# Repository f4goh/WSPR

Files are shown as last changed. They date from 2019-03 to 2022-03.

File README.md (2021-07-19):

**WSPR beacon on breadboard**

[link to hamprojects web site](https://hamprojects.wordpress.com/2019/06/02/wspr-beacon/)

*f4goh@orange.fr*

**Add FST4W for Antonio (IK1HGI) and new library for OLED**

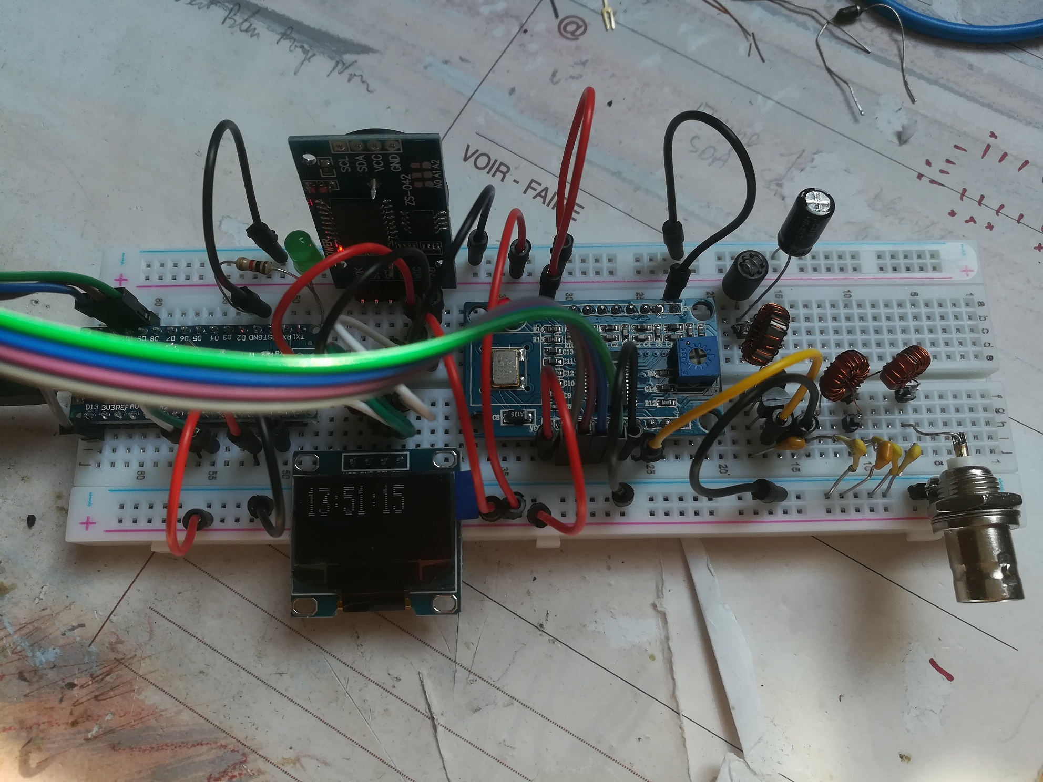
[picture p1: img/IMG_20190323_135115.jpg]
wspr wspr finsished


## Wiring ##

- Wire the schematics below

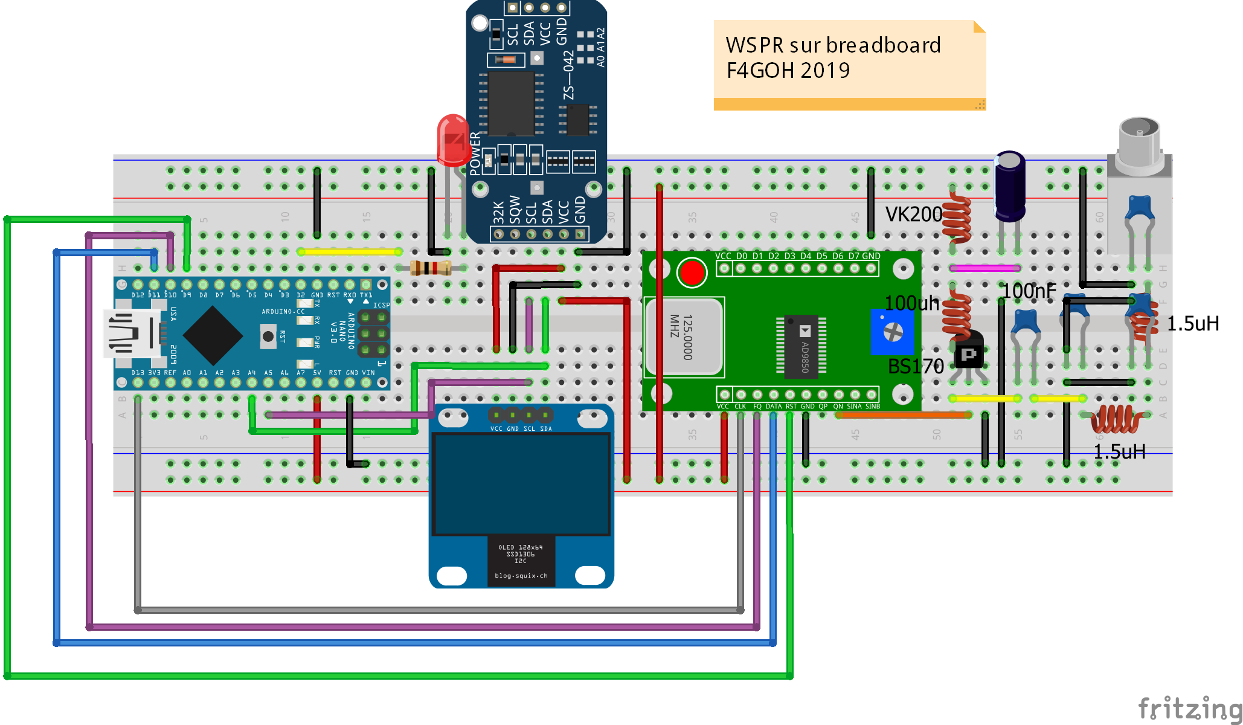
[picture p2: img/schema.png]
sch


- Adjust output filter as filter design calculation

[filter design](http://tonnesoftware.com/svcfilter.html) 

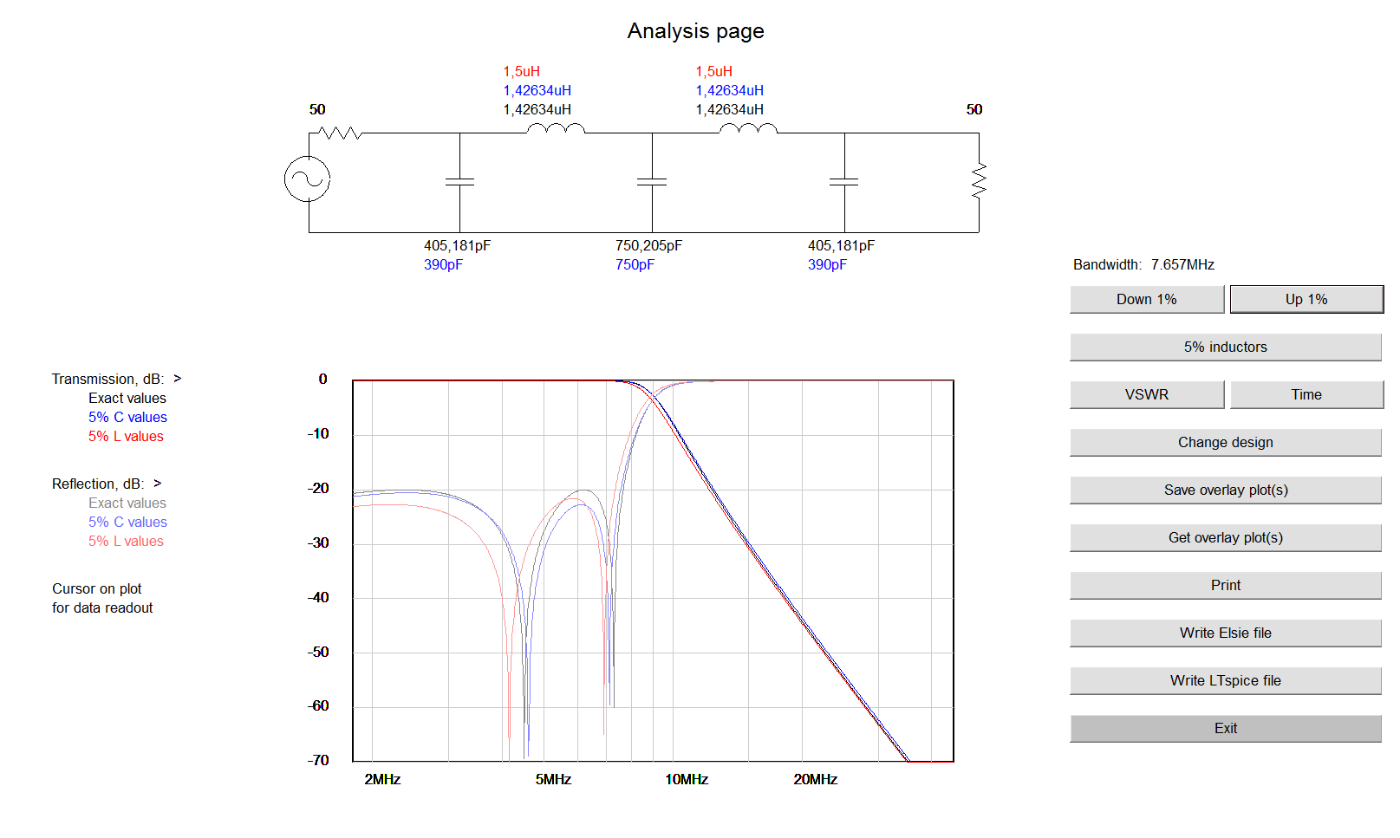
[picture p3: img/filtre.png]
filter


- Use mini tore calculator to find inductor turns

[mini tore calculator](https://constructions.f6fkn.com/downloads/minirk12-install.exe) 

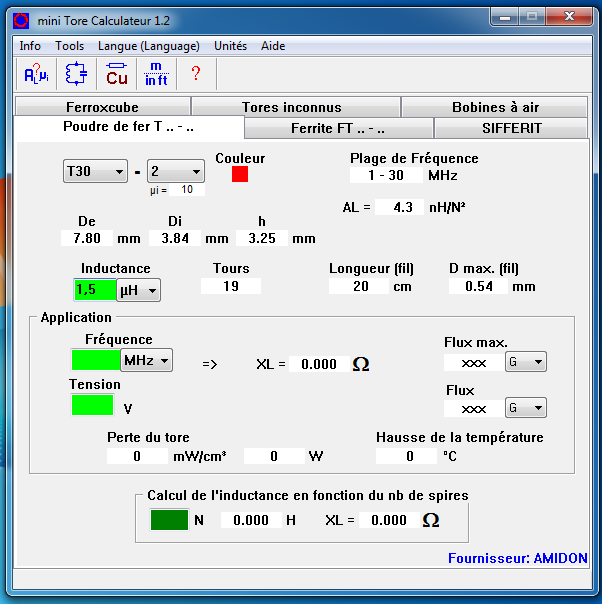
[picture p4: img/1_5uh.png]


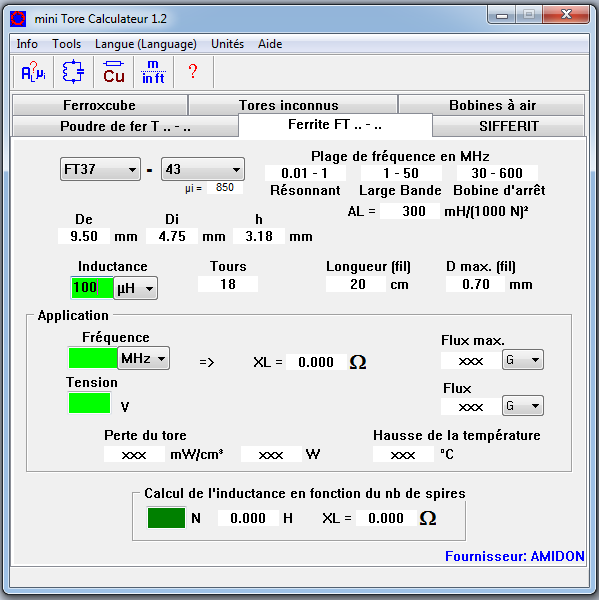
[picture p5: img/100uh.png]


- Check filter with a VNA (optional)

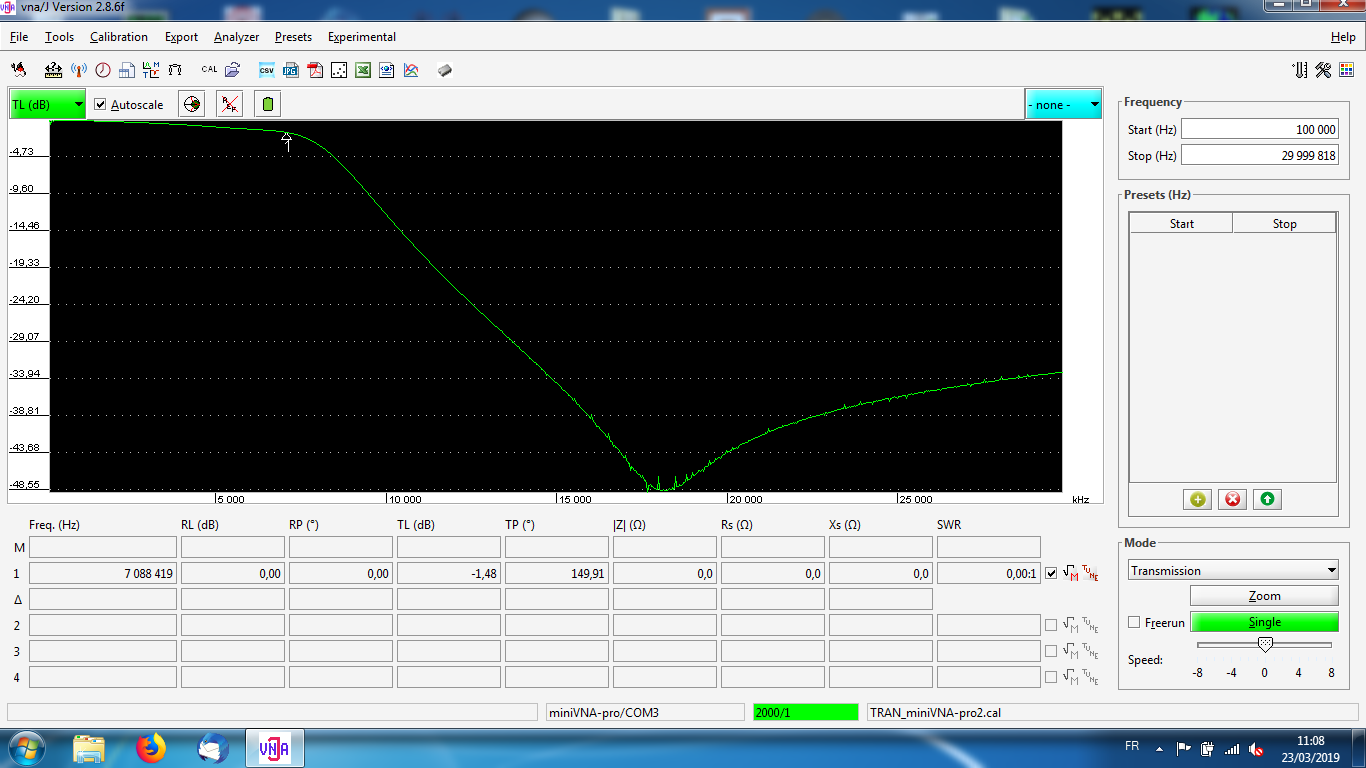
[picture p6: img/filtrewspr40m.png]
vna


## Programming ##

- Copy libraries files into Arduino/library folder

- run wspr.bat put your callsign, locator and power and generate symbols.

symbols wspr_gen

- Paste symbols from symbols.txt into WsprSimple.ino with commas

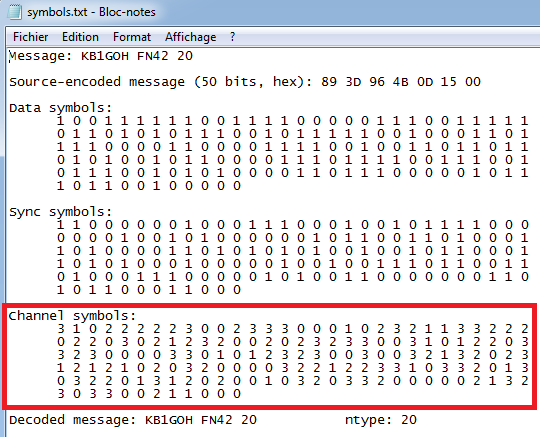
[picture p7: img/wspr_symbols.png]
symbols wspr_symbols


```c++
	int wsprSymb[] = {3, 3, 0, 0, 0, 2, 0, 2, 1, 2, 0, 2, 3, 3, 1, 0, 2, 0, 3, 0, 0, 1, 2, 1, 1, 3, 1, 0, 2, 0, 0, 2, 0, 2, 3, 2, 0, 1, 2, 3, 0, 0, 0, 0,
	                  2, 2, 3, 0, 1, 3, 2, 0, 3, 3, 2, 3, 2, 2, 2, 1, 3, 0, 1, 0, 2, 0, 2, 1, 1, 2, 1, 0, 3, 2, 1, 2, 3, 0, 0, 1, 2, 0, 1, 0, 1, 3, 0, 0,
	                  0, 1, 3, 2, 1, 2, 1, 2, 2, 2, 3, 0, 0, 2, 2, 2, 3, 2, 0, 1, 2, 0, 3, 3, 1, 2, 3, 3, 0, 2, 1, 3, 0, 3, 2, 2, 0, 3, 3, 1, 2, 0, 0, 0,
	                  2, 1, 0, 1, 2, 0, 3, 3, 2, 2, 0, 2, 2, 2, 2, 1, 3, 2, 1, 0, 1, 1, 2, 0, 0, 3, 1, 2, 2, 2
	                 };
```

- Adjust frequency

```c++
#define frequence 7040100
long factor = -1500;
```

## Usage notes ##
	
- Program Arduino Nano
- Adjust RTC clock by typing "h" key on serial monitor

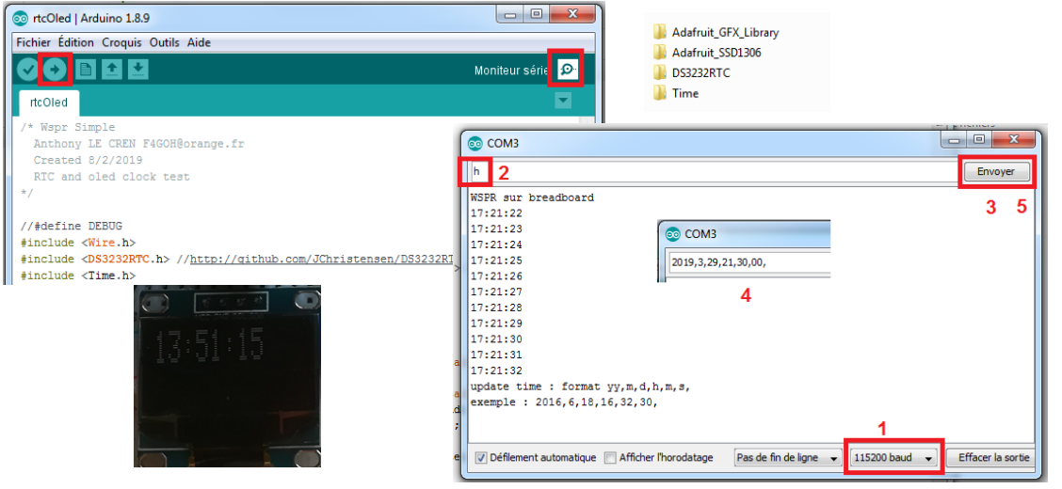
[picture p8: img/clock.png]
clock


- Connect any HF antenna

Beacon transmit every 2 min, monitor transmission with your receiver and 
adjust frequency "factor" offset if there is outside the WSPR band

- Enjoy WSPR beacon.

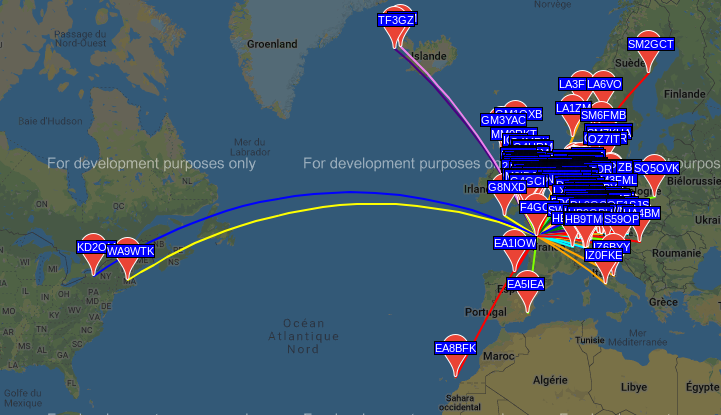
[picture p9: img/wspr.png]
map


the src directory contains other programs like :

- Rtty, PSK, QPSK, Hellschreiber, JT65, JT9, WSPR and FT8 encoding exemples

- And [FSQCall](https://www.qsl.net/zl1bpu/MFSK/FSQweb.htm) beacon test

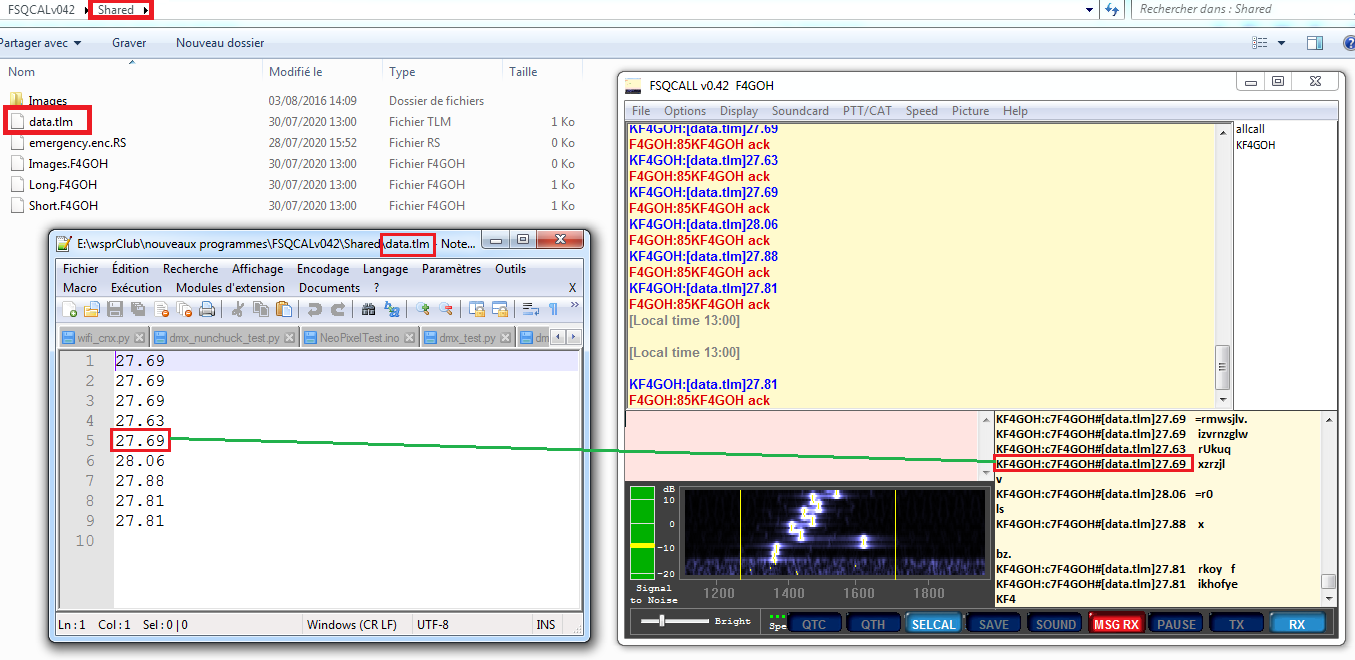
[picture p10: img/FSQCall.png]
fsq


- Telemetry is saved into FSQCALv042\Shared\data.tlm
- File can be changed into FSQEncode.ino

73

Anthony

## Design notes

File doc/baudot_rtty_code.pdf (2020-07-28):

RTTY code | Anthony : F4GOH
features : | Tones: (standard, but adjustable)
Modulation : FSK | Level 0 : Low frequency : Mark : 2125 Hz
Speed : 45.45 bauds
1/6 s for 1 Char

Level 1 : High frequency : Space : 2295 Hz Space = Mark + Shift = 2125 Hz + 170 Hz
Transmission : Asynchronous | 1 Start bit; 5 data bits; 1.5 or 2 Stop bits
characters : Baudot Code | 360 characters per minute maximum
5 data bits (reduced format)
Restricted number of characters. No check
code. 300 Hz bandwidth

Usual frequencies: Center of activity (No fixed freq.) 14,080 Mhz / 14,100 Mhz
7,040 Mhz /7,050 Mhz
Self-taught and French engineer, Émile Baudot (1845-1903), improved Morse code by inventing a binary code for transmitting teletypes. The term "baud" is derived from its name.
Code | Characters
binary | decimal | Letter mode | Symbol mode
00000 | 0 | NULL
00001 | 1 | E | 3
00010 | 2 | LF
00011 | 3 | A | -
00100 | 4 | SP | SP
00101 | 5 | S | BEL
00110 | 6 | I | 8
00111 | 7 | U | 7
01000 | 8 | CR
01001 | 9 | D | $
01010 | 10 | R | 4
01011 | 11 | J | '
01100 | 12 | N | ,
01101 | 13 | F | !
01110 | 14 | C | :
01111 | 15 | K | (
Code | Characters
binary | decimal | Letter mode | Symbol mode
10000 | 16 | T | 5
10001 | 17 | Z | "
10010 | 18 | L | )
10011 | 19 | W | 2
10100 | 20 | H | #
10101 | 21 | Y | 6
10110 | 22 | P | 0
10111 | 23 | Q | 1
11000 | 24 | O | 9
11001 | 25 | B | ?
11010 | 26 | G | &
11011 | 27 | Symbol mode enable
11100 | 28 | M | .
11101 | 29 | X | /
11110 | 30 | V | ;
11111 | 31 | Letter mode enable
Example of frame RTTY : « TEST » word emission and Cr, Lf

Description:
We start by sending an NL1 for a few ms, then the Start bit arrives at the NL0. The 5 data bits are then sent starting with the least significant bit. We end with the stop bit and a half at NL1. In this example, we send code 31 which corresponds to letter mode. If you want to send numbers, you must first signal it and transmit the code 27

The decoding software
performs digital filtering on the 2 Mark and Space
frequencies in order to
recreate the binary frame.

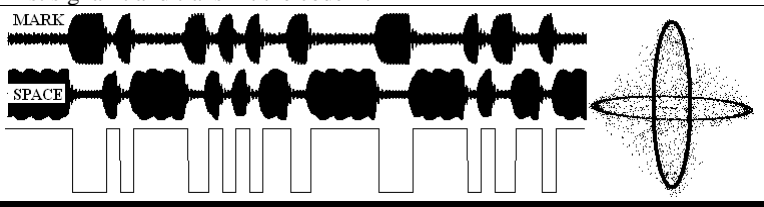
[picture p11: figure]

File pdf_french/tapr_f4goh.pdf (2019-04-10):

Standalone HAM modulation generator

Anthony LE CREN, F4GOH
47 rue de l’avenir
72220 TELOCHE
FRANCE
f4goh@orange.fr

Abstract

I have always been interested in radio modulations like RTTY, PSK, WSPR etc…and especially to know how it's coded. the asset of these modulations is understanding the DDS (Direct Digital Synthesis) operating principle. Then, you will be able to generate any modulation.

Introduction

The idea is to generate RTTY, Hellschreiber, WSPR, CW, PSK and QPSK 31,63,125 without PC. These audio frequency modulations are delivred by an Arduino. The TRX are controlled by CIV system and an DS3231 RTC synchronize time to transmit WSPR every even minutes. The cost is about 20$. I use a Arduino Nano, but it can be work with an Arduino Uno.

Conclusion

It was a pleasure to study DDS and modulation generation. This project was designed essentially for makers. Adapt it as you want. If you have any questions, send me an email.

Reference

https://hamprojects.wordpress.com/

https://github.com/f4goh/MODULATION

http://www.analog.com/media/en/training-seminars/tutorials/MT-085.pdf

http://www.arrl.org/psk31-spec

http://www.g4jnt.com/wspr_coding_process.pdf

https://brainwagon.org/2012/01/11/hellduino-sending-hellschreiber-from-an-arduino/

http://www.johnloomis.org/digitallab/audio/audio3/tut_dds.pdf

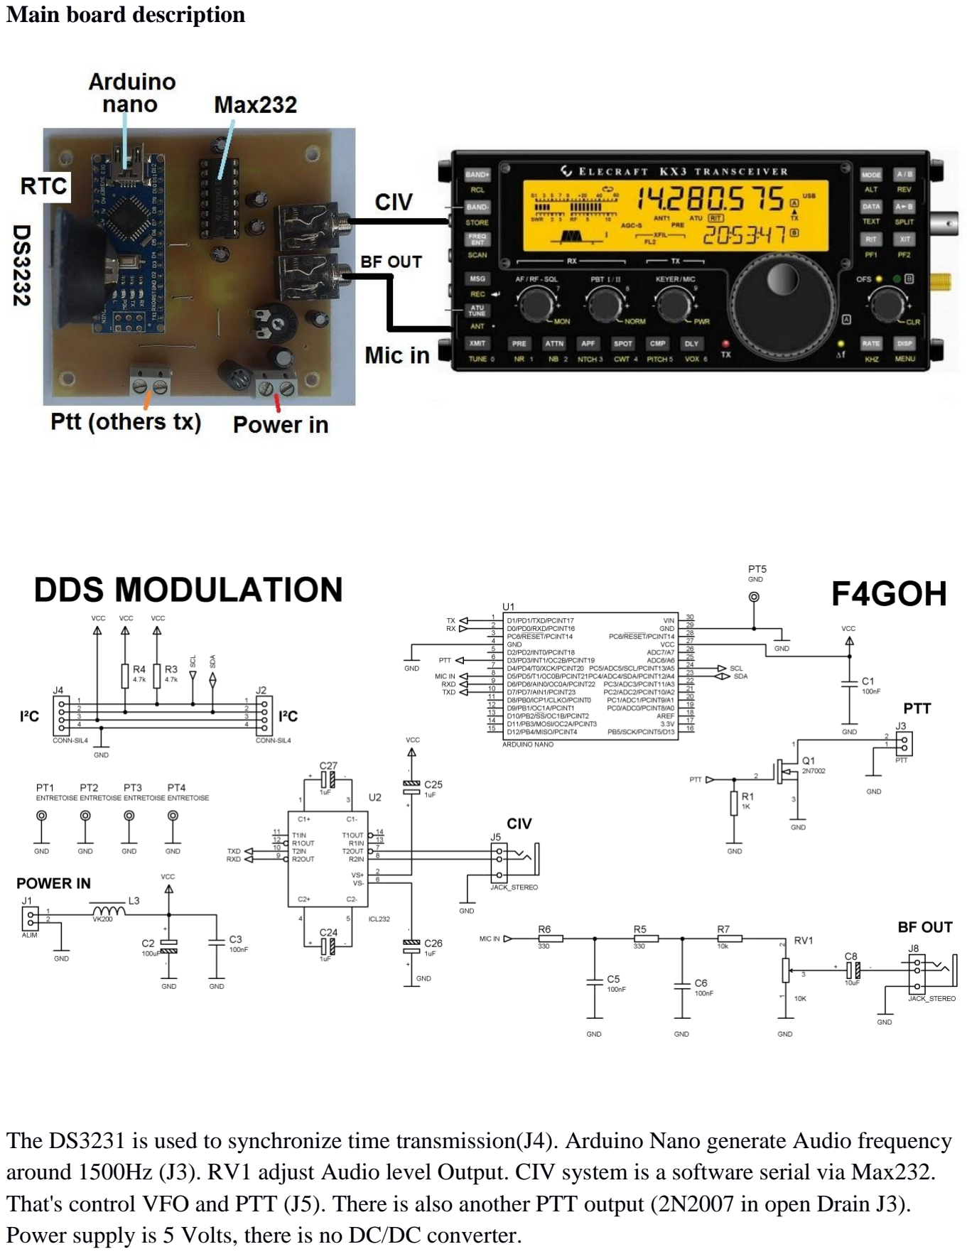
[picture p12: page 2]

Main board description

The DS3231 is used to synchronize time transmission(J4). Arduino Nano generate Audio frequency around 1500Hz (J3). RV1 adjust Audio level Output. CIV system is a software serial via Max232. That's control VFO and PTT (J5). There is also another PTT output (2N2007 in open Drain J3). Power supply is 5 Volts, there is no DC/DC converter.

The audio sinus frequency is generated by Arduino PWM, so a low pass filter is required.

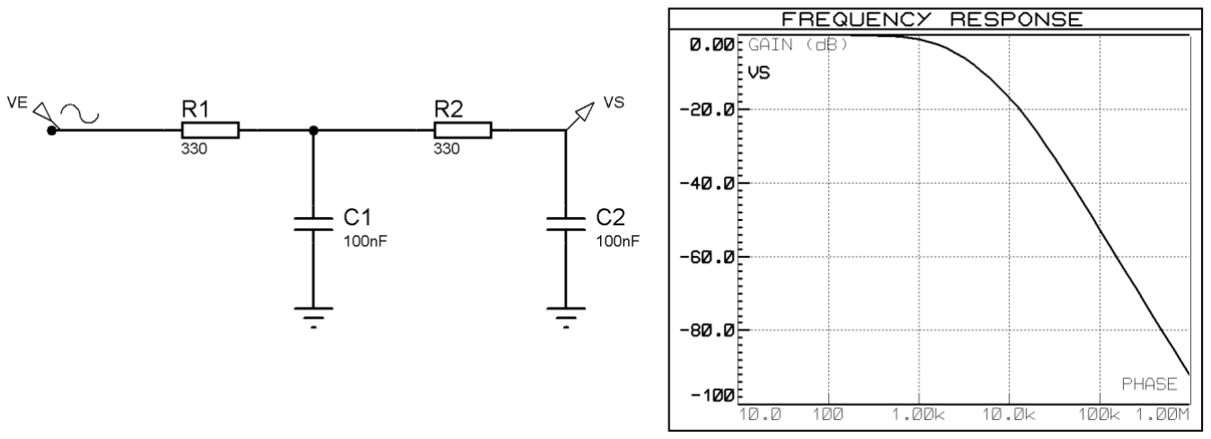
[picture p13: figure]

Direct digital synthesis

Usually, a sinusoidal table sampled in constant frequency makes it possible to obtain a single frequency. It is not enough, because it is necessary to generate a frequency between 1000 and 1500 hertz with a step of 1.4548 Hertz (WSPR). You can not overload flash memory with as many sinus tables as necessary. So how to generate different frequencies with only one lookup table?

The method is described by Analog Devices or National Instruments.

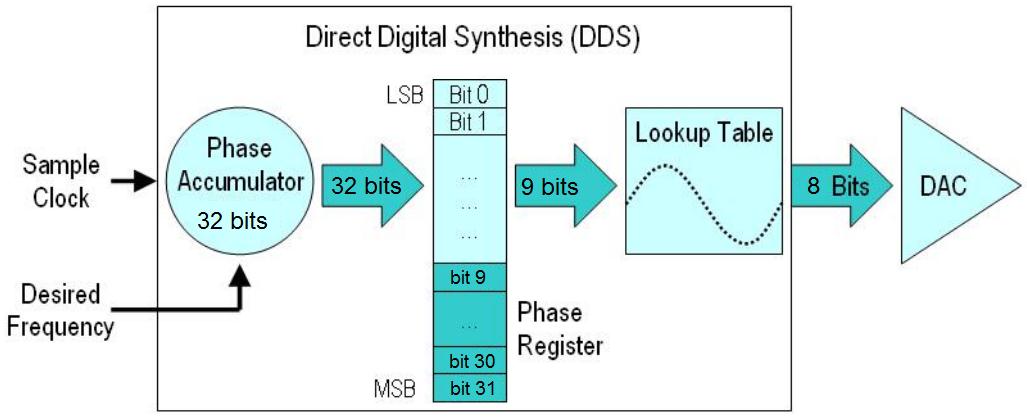
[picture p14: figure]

I just adapt it for an Arduino to generate WSPR, CW, PSK and QPSK 31,63,125 modulations.
I use 32 bits phase accumulator and 9 bits pointer to lookup table. The PWM is used as DAC (Digital Analog Converter)

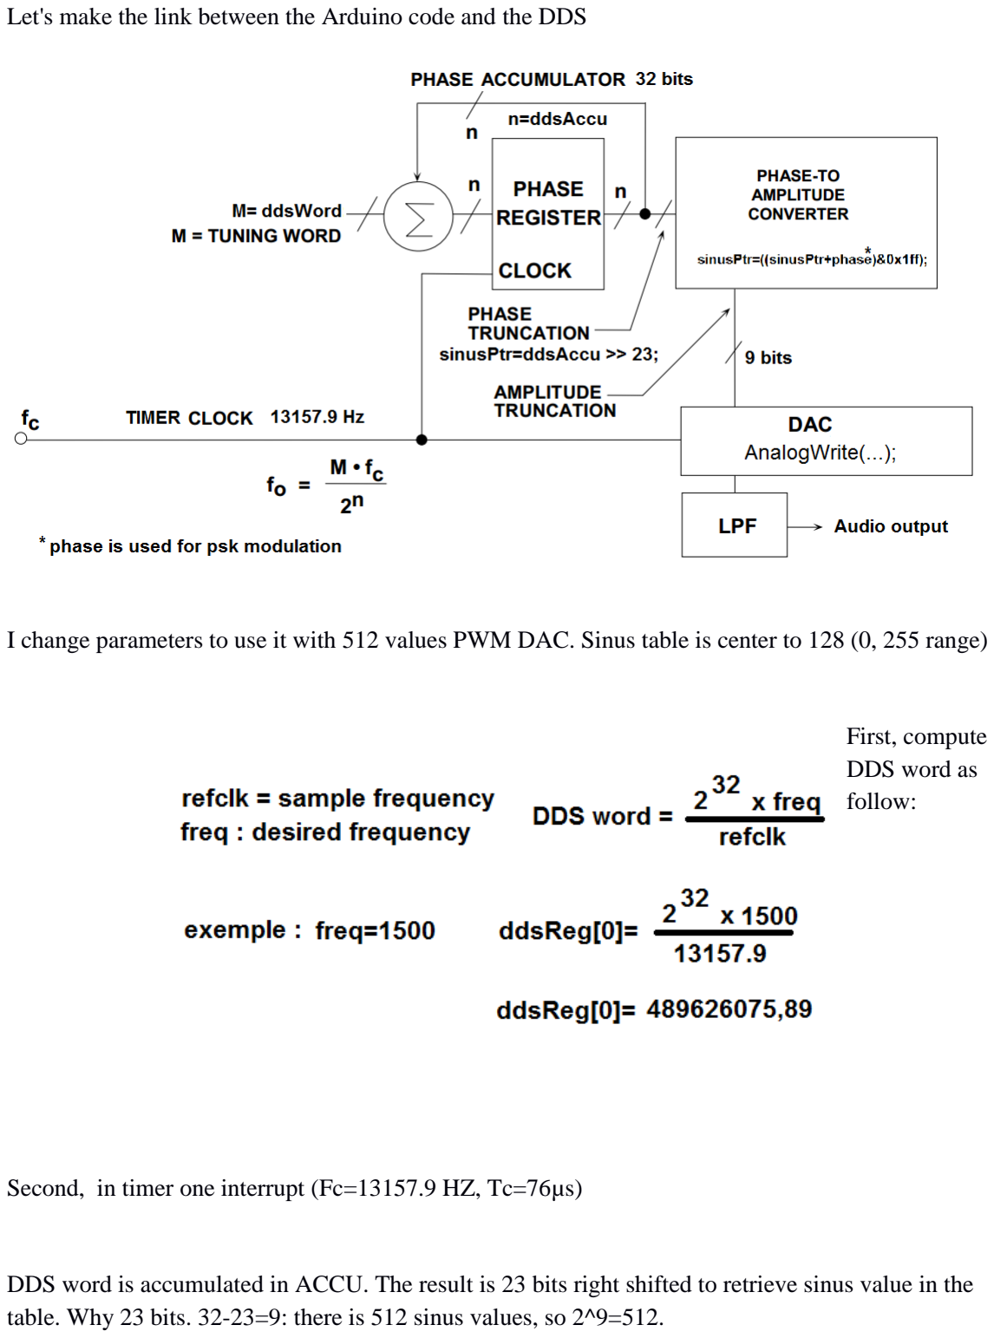
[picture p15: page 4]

Let's make the link between the Arduino code and the DDS

I change parameters to use it with 512 values PWM DAC. Sinus table is center to 128 (0, 255 range)

First, compute
DDS word as
follow:

Second, in timer one interrupt (Fc=13157.9 HZ, Tc=76µs)

DDS word is accumulated in ACCU. The result is 23 bits right shifted to retrieve sinus value in the table. Why 23 bits. 32-23=9: there is 512 sinus values, so 2^9=512.

DDS programming

void MODULATION::sinus() | //timer one irq
{
const static byte sinusTable[512] PROGMEM = {128,129 | };

ddsAccu=ddsAccu+ddsWord; // soft DDS, phase accu with 32 bits sinusPtr=ddsAccu >> 23;
sinusPtr=((sinusPtr+phase)&0x1ff); | //add phase for psk or qpsk

analogWrite(bf_pin,pgm_read_byte(&(sinusTable[sinusPtr]))); //DAC
countPtr++; | //count interrupt for time generation
}

unsigned long MODULATION::computeDdsWord(double freq) {
return pow(2,32)*freq/refclk;
}
void MODULATION::send_bit(int tempo) | //bitrate modulation counter
{
countPtr=0;
int countPtrPrec=0;
while(countPtrPrec<tempo){
if (countPtrPrec<countPtr) { countPtrPrec=countPtr;
}
}
countPtr=0;
digitalWrite(13,digitalRead(13)^1); | //scope irq measurement.
}

tempo variable is a irq count order. For example if i want to generate a frequency during 0,682 s, the calculation is:
Numbrer irq required = FC*0,682 | //13157.9*0.682=8973

Software description

The WSPR, CW, PSK, QPSK 31,63,125 and DDS generator are implemented in MODULATION library on Github.

WSPR_TRX.ino is an experimental program and very short.

Update RTC before begin transmission :
update time: format yy,m,d,h,m,s
example: 2016,6,18,16,32,30,

Program send audio signal every minute according to modulation table

1 | RTTY
2 | Hellschreiber
3 | WSPR
4 | CW
5 | PSK and QPSK 31,63,125

txing(3); // send WSPR modulation

CIV is used for KX3 TRX. Change sentence according to your TRX.

Realization

There are two ways to test it. Go on Github and made the PCB or use a breadboard.

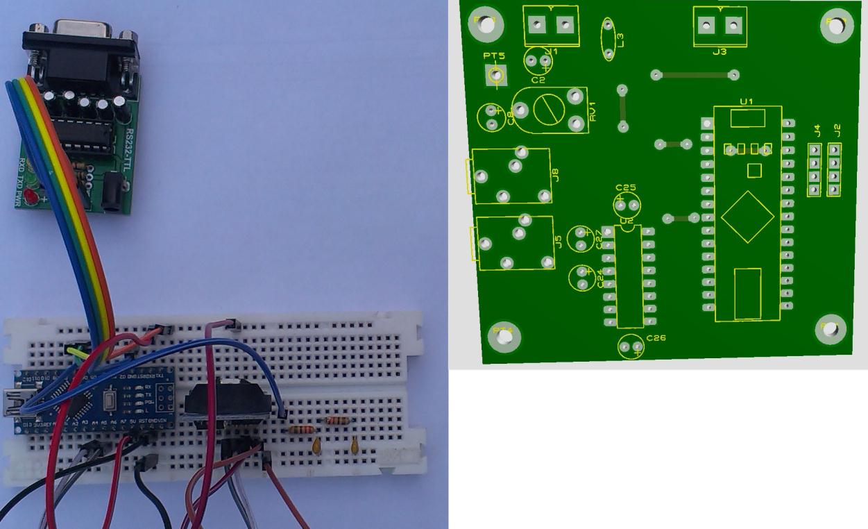
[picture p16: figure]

Results on wsprnet.org with a KX3, 1W, 40 meters on a dipole.

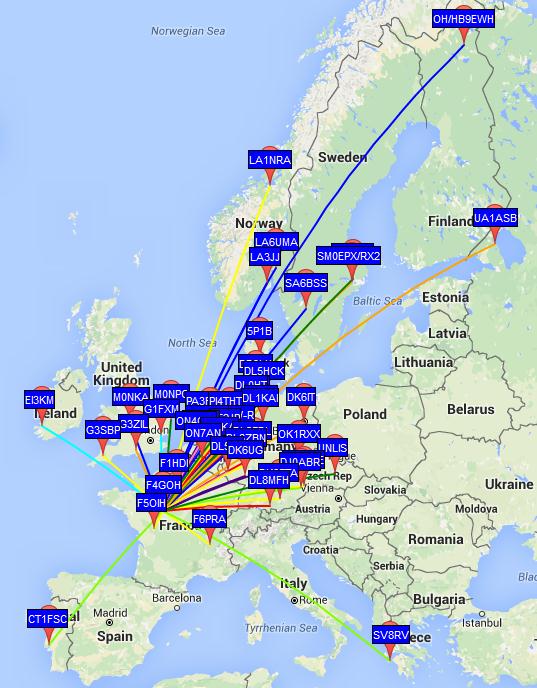
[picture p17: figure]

Anthony Le Cren F4GOH has been licensed since 2010 and loves to experiment with Arduino applied to the radio. He is a professor of Computer Science at Gabriel Touchard High School in Le Mans, France. Anthony has written numerous articles in different countries (France, GB, USA, Belgium, Italy, Spain, Germany, Poland) and maintains a web page of Amateur Radio Projects at: https://hamprojects.wordpress.com/

You can reach Anthony at: f4goh@orange.fr

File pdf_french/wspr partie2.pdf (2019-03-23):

# Utilisation de l’Arduino Nano et de

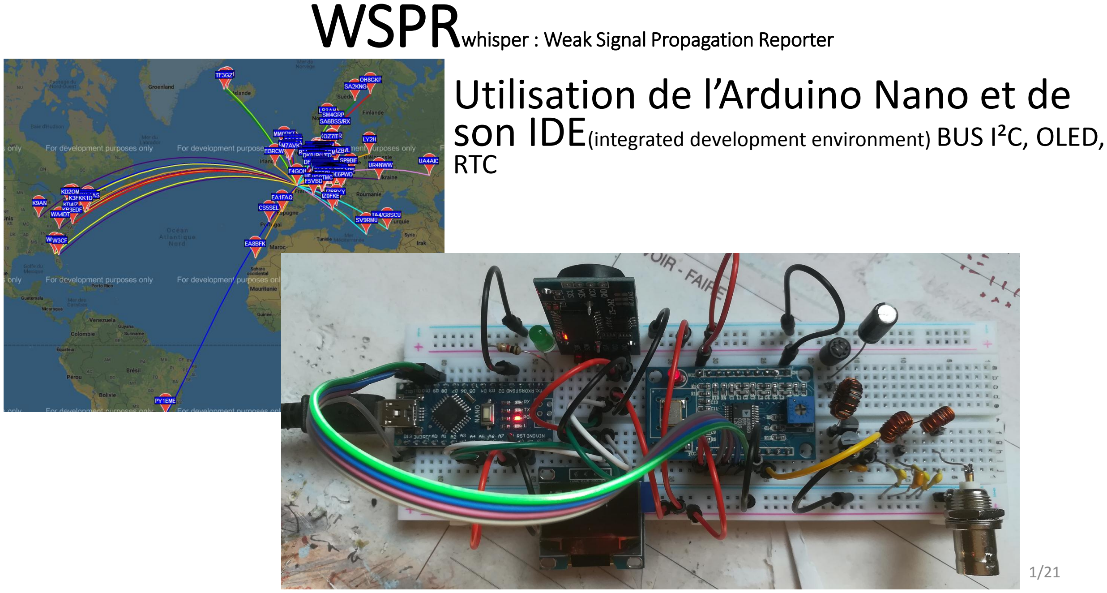
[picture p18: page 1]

WSPRwhisper : Weak Signal Propagation Reporter

son IDE(integrated development environment) BUS I²C, OLED,

## RTC

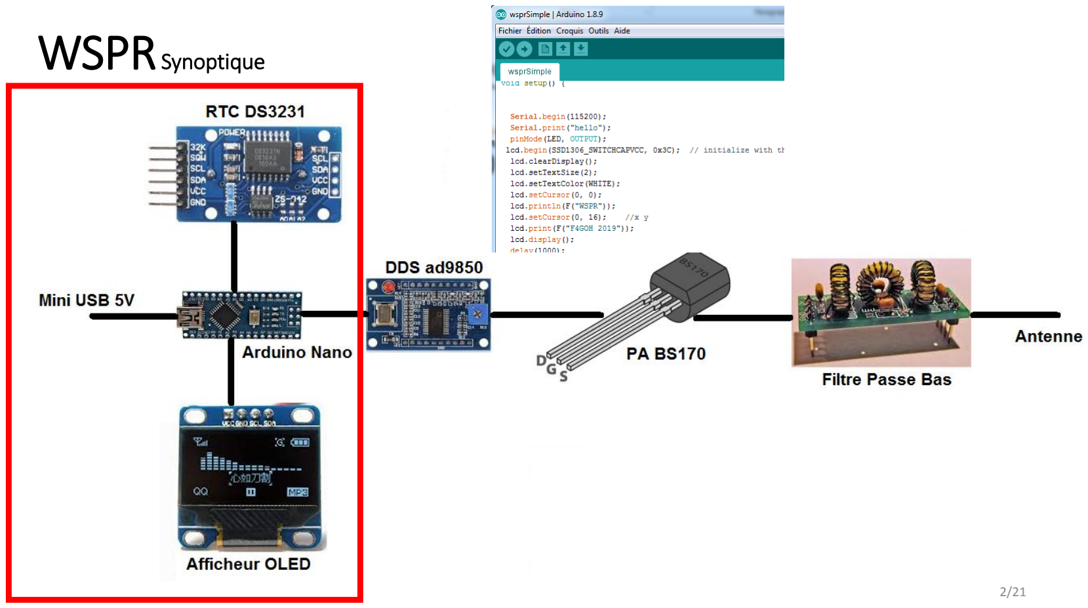
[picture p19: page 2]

WSPRSynoptique

WSPRLa gamme des Arduinos

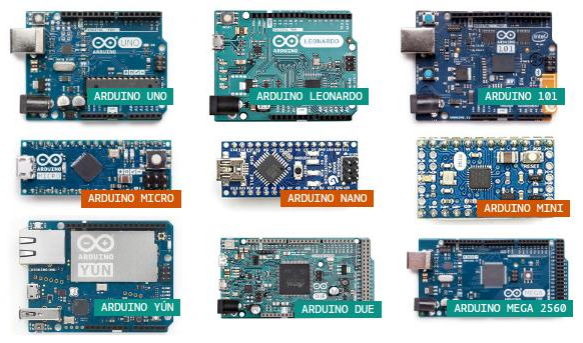
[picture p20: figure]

WSPR Autres cartes utilisant le même IDE

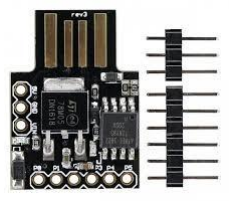
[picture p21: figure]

Digispark, STM32 Nucleo, ESP8266,

# ESP32, TEENSY etc…

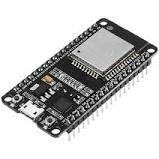
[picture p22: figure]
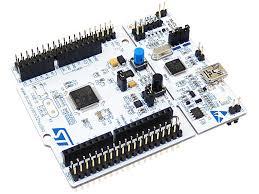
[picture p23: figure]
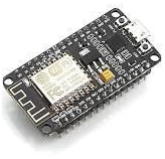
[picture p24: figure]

# Ebay

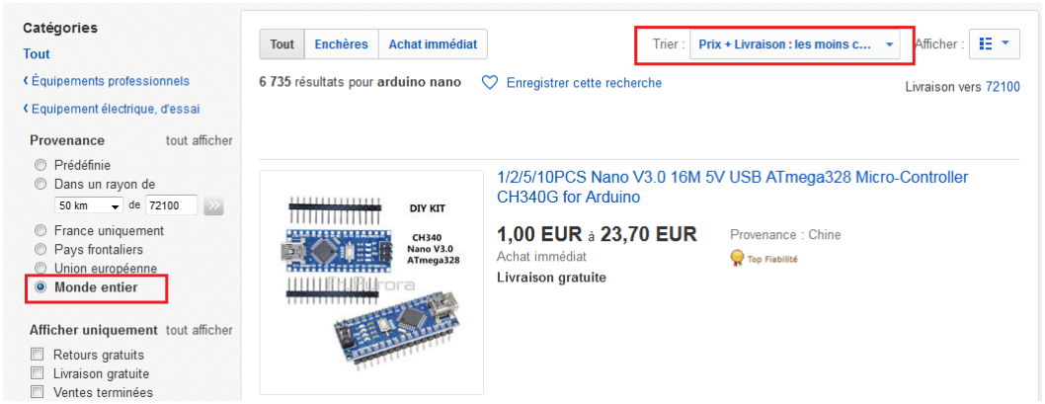
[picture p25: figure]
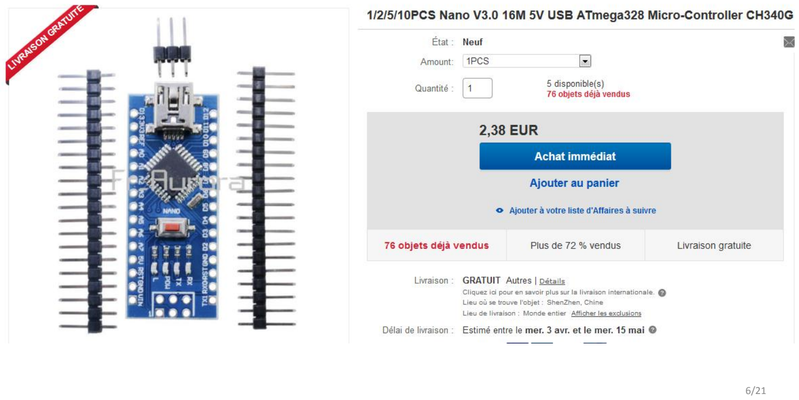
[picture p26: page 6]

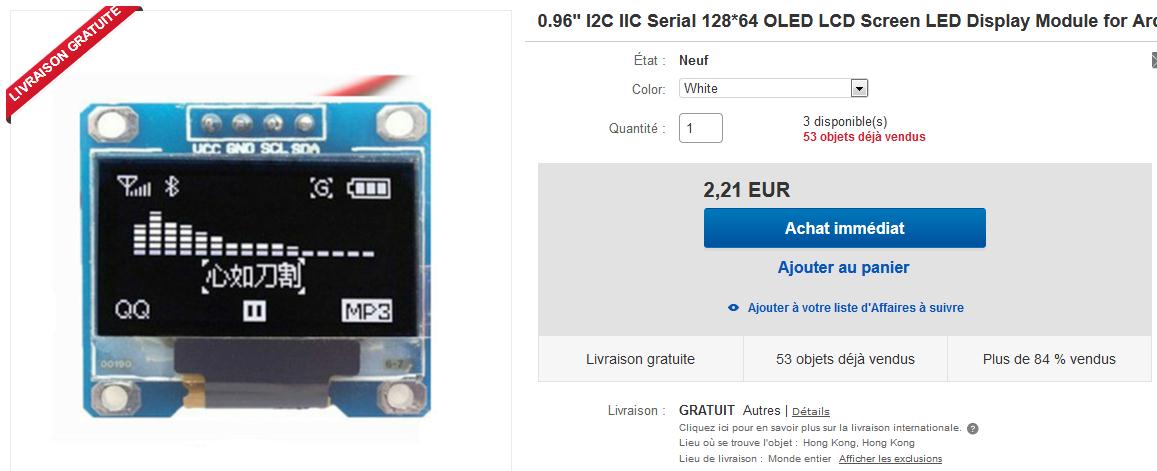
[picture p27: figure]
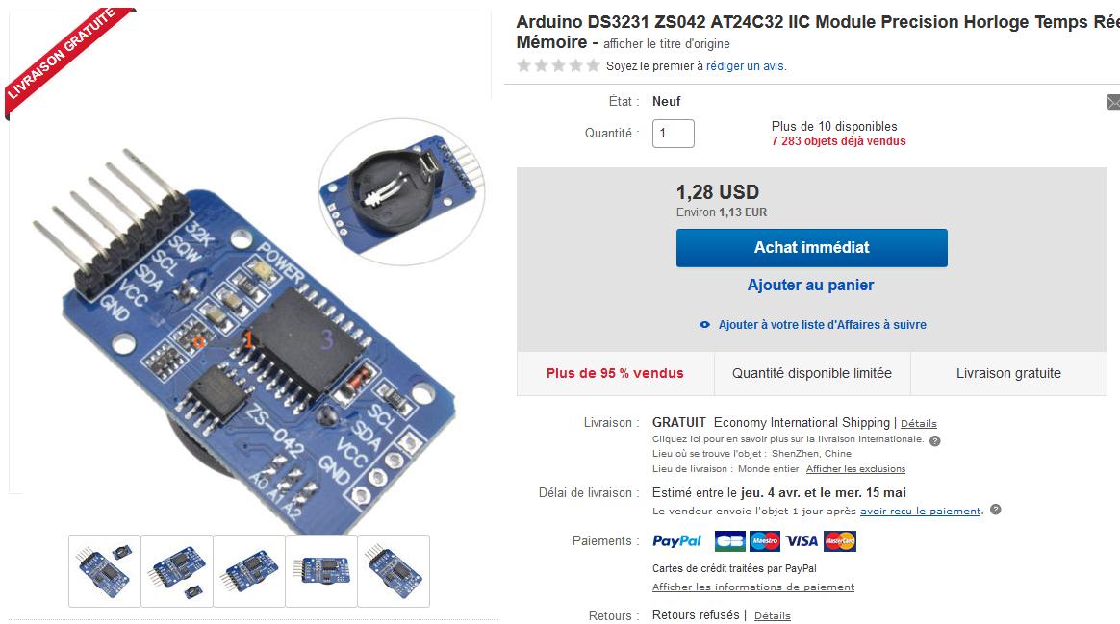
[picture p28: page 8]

# La breadboard (plaque à essais)

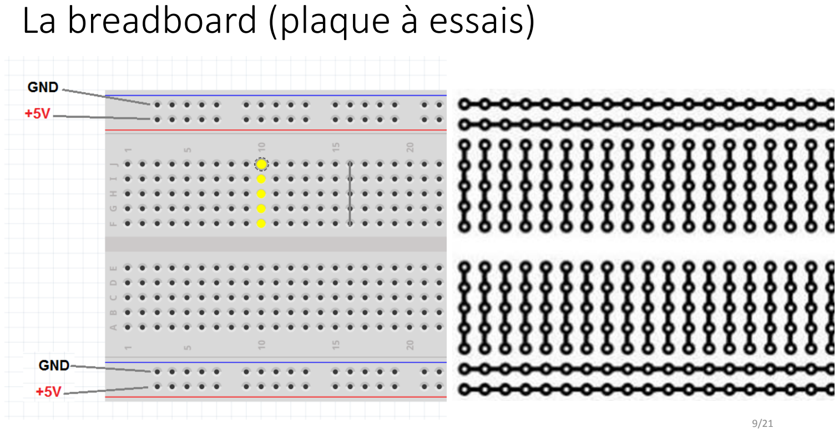
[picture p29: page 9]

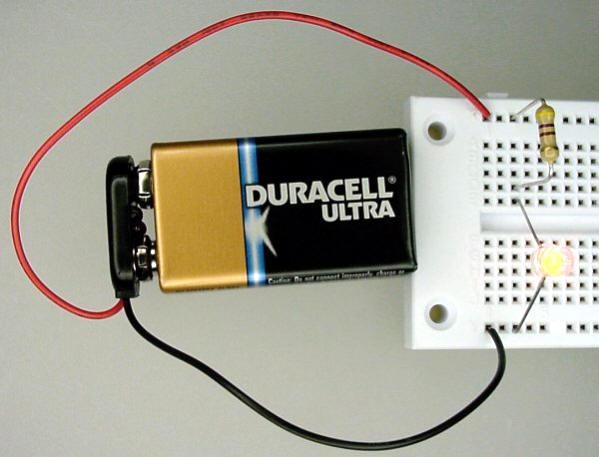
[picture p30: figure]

# Câbler la Led sur la broche 2 de l’Arduino nano

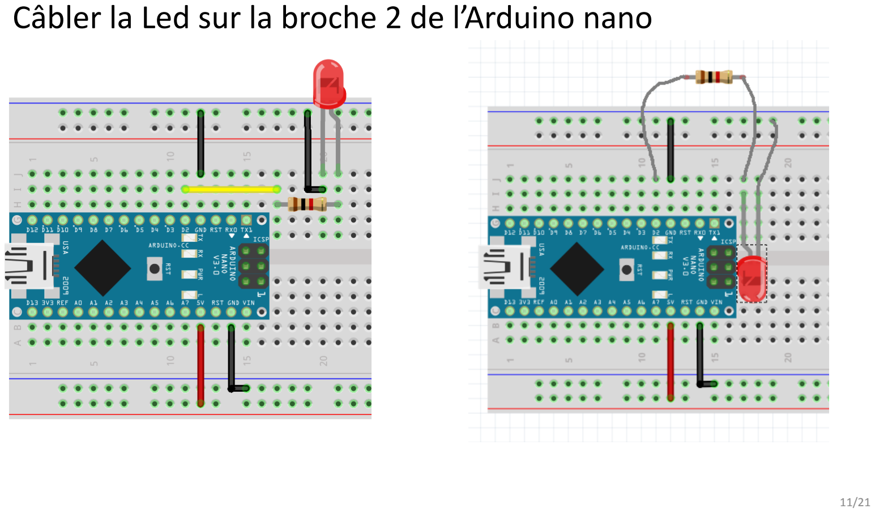
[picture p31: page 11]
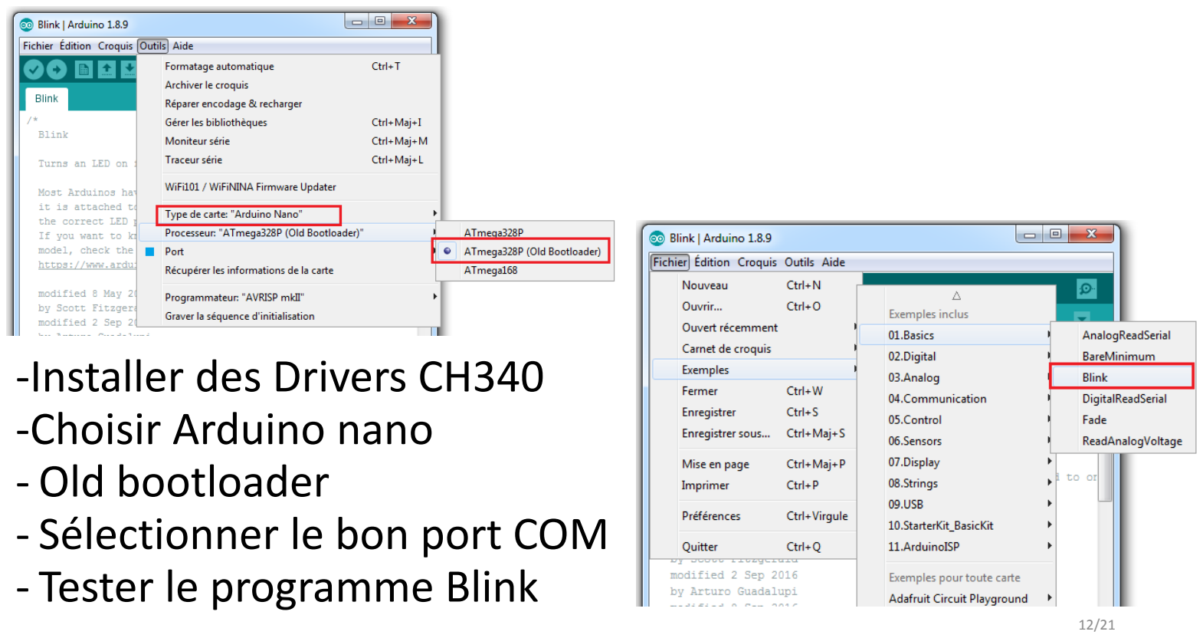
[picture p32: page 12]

-Installer des Drivers CH340 -Choisir Arduino nano - Old bootloader - Sélectionner le bon port COM - Tester le programme Blink

# - Après un 1er test de programmation, utiliser la broche 2 de l’arduino pour faire clignoter la LED

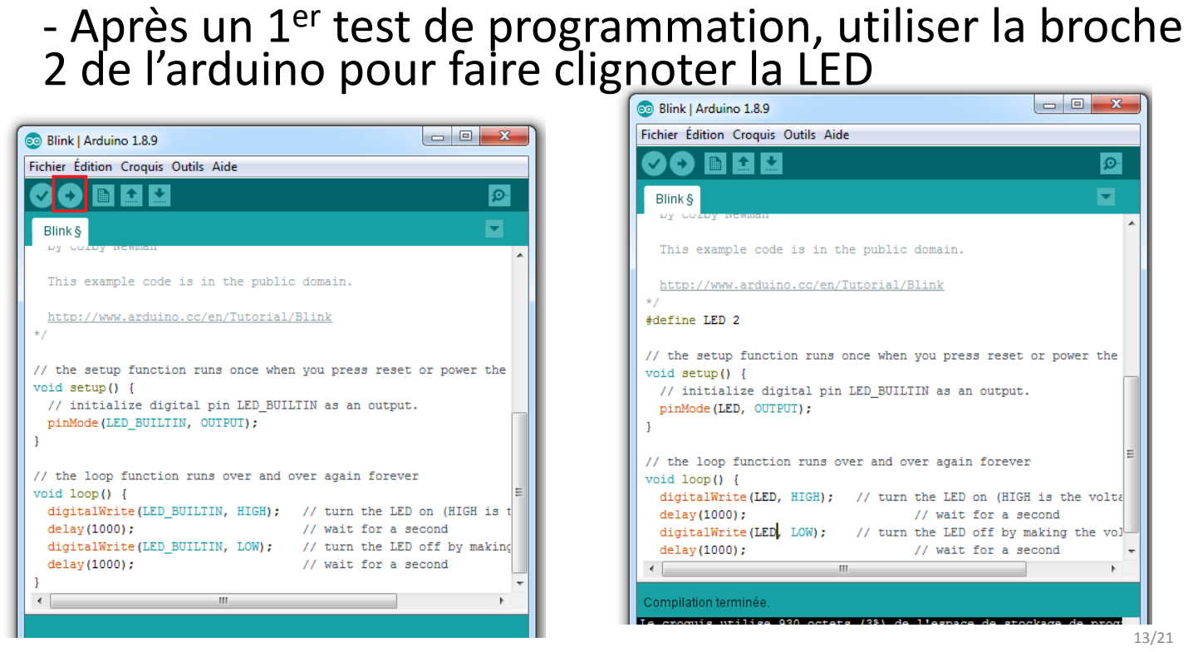
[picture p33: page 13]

# Le Bus I2C

Philips en 1982

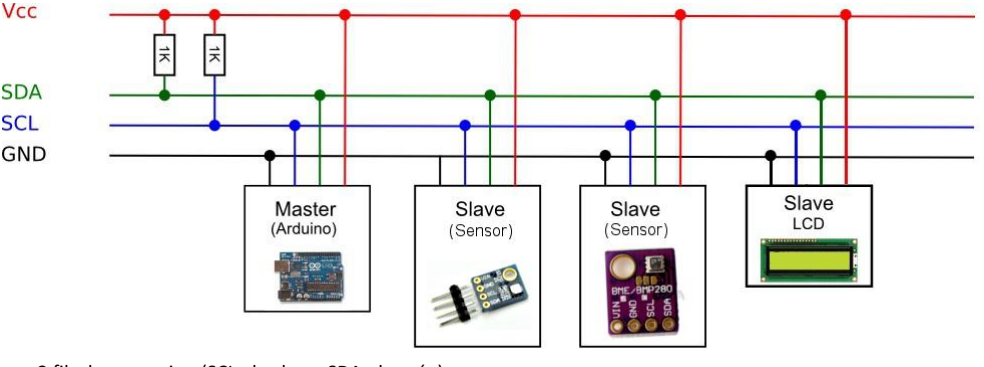
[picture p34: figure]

- 2 fils de connexion (SCL : horloge, SDA: donnée)
- 127 adresses ou esclave possibles
- Vitesse 100kb/s à 400kb/s (Arduino)
- Transmission synchrone

# RTC

ds3231


https://www.maximintegrated.com/en/design/tools/calculators/product-design/rtc.cfm | 15/21


https://www.saleae.com/fr/downloads/


## - Allez sur https://github.com/f4goh/WSPR - Télécharger le fichier ZIP


- Copier les librairies dans le répertoire
- C:\Users\[nom du pc]\Documents\Arduino\libraries
- Programmer le fichier rtcOled
- Ouvrir le moniteur série, appuyer sur le touche « h » pour mettre à jour l’horloge suivant le format suivant : yy,m,d,h,m,s,


# La prochaine séance


## DDS HF programmable

AD9850


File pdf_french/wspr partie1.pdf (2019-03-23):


WSPRwhisper : Weak Signal Propagation Reporter

Joe Taylor (K1JT)
Astrophysicien américain
Prix Nobel de physique
(1993)

WSPRLe développement


# 1) Présentation du projet WSPR

# 2) Utilisation de l’Arduino Nano et de

son IDE(integrated development environment) BUS I²C, OLED, RTC

# 3) Fonctionnement du DDS (AD9850) et protocole WSPR

# 4) PA et filtre passe bas

# 5) Assemblage et test du PCB final

- Protocole écrit par Joe Taylor, K1JT,
- TX RX en faible puissance ,
- Test de la propagation.

Emission :

- INDICATIF,
- LOCATOR,
- PUISSANCE dbm.
- Durée : 110 secondes toutes les minutes paires
- Besoin d’une horloge

Réception :

- Décoder des signaux S/B= −28 dB ,
- Les stations envoient les rapports de transmission via internet dans une base de donnée WSPRnet,
- Cartographie .

WSPR: Pourquoi faire ?

WSPR: Cartographie | http://wsprnet.org/drupal/


## WSPR: Emission/Réception https://physics.princeton.edu/pulsar/k1jt/wsjtx.html


# Logiciel WSJT-X intègre -WSPR

- FT8
-JT65
-JT9

# Etc…

WSJT-X: Comment télécharger et installer le programme



WSPREmetteurs autonomes


WSPREmetteur autonome


WSPRSynoptique

# Utilisation de l’Arduino Nano et de son IDE


WSPRPartie 2

- Présentation du BUS I²C

## - Afficheur OLED et RTC

WSPRPartie 3

# Fonctionnement du DDS (AD9850) - Protocole WSPR - Analyse fréquentielle avec le CMU


# PA et filtre passe bas (SVC Filter designer, VNA)


WSPRPartie 4

# Assemblage et test du PCB final


WSPRPartie 5


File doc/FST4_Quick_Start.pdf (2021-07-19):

### Quick-Start Guide to FST4 and FST4W

Steve Franke, K9AN; Bill Somerville, G4WJS; and Joe Taylor, K1JT
WSJT-X 2.3.0 introduces FST4 and FST4W, digital protocols designed particularly for the LF and MF bands. On these bands their fundamental sensitivities are better than other WSJT-X modes with the same sequence lengths, approaching the theoretical limits for their rates of information throughput. FST4 is optimized for two-way QSOs, while FST4W is for quasi-beacon transmissions of WSPR-style messages. FST4 and FST4W do not require the strict, independent time synchronization and phase locking of modes like EbNaut.
The new modes use 4-GFSK modulation and share common software for encoding and decoding messages. FST4 offers T/R sequence lengths of 15, 30, 60, 120, 300, 900, and 1800 seconds, while FST4W omits the lengths shorter than 120 s. Submodes are given names like FST4-60, FST4W-300, etc., the appended numbers indicating sequence length in seconds. Message payloads contain either 77 bits, as in FT4, FT8, and MSK144, or 50 bits for the WSPR-like messages of FST4W. Message formats displayed to the user are like those in the other 77-bit and 50-bit modes in WSJT-X. Forward error correction uses a low density parity check (LDPC) code with 240 information and parity bits. Transmissions consist of 160 symbols: 120 information-carrying symbols of two bits each, interspersed with five groups of eight predefined synchronization symbols.
Basic parameters of all FST4 and FST4W submodes are summarized in the table below. Threshold sensitivity (SNR in 2500 Hz bandwidth yielding 50% probability of decode) was measured for each submode using simulations over the additive white Gaussian noise (AWGN) channel. As with other recently developed modes in WSJT-X, a feature called a priori (AP) decoding can improve sensitivity by several additional dB as information is accumulated during a standard minimal QSO or FST4W operating session.
T/R period (s) | Symbol length (s) | Tone Spacing (Hz) | Occupied Bandwidth (Hz) | FST4 SNR (dB) | FST4W SNR (dB)
15 | 0.060 | 16.67 | 67.7 | -20.7
30 | 0.140 | 7.14 | 28.6 | -24.2
60 | 0.324 | 3.09 | 12.4 | -28.1
120 | 0.683 | 1.46 | 5.9 | -31.3 | -32.8
300 | 1.792 | 0.56 | 2.2 | -35.3 | -36.8
900 | 5.547 | 0.180 | 0.72 | -40.2 | -41.7
1800 | 11.200 | 0.089 | 0.36 | -43.2 | -44.8

FST4-60 is about 1.7 dB more sensitive than JT9, largely because it uses multi-symbol block detection where appropriate. With AP decoding in FST4 the difference can be as much as 4.7 dB. FST4-120 and the longer sequence lengths are proportionally more sensitive. FST4W-120 is about 1.4 dB better than standard WSPR, and with its 30-minute sequences FST4W-1800 reaches a threshold SNR of nearly -45 dB. We strongly recommend that users of JT9 and WSPR on the LF and MF bands should migrate to using FST4 and FST4W, instead.
You may think of other applications for the new modes beyond those discussed here. Keep in mind that these are very narrow-band modes; achieving the sensitivities listed in the table requires that oscillator drifts and path-induced Doppler shifts must be less than the tone spacing, over the full sequence length. As one example of a different application, the short-sequence submode FST4-15 has been found very effective on 50 MHz ionospheric scatter paths. At the opposite extreme of transmission length, VK7MO and VK7ZBX have had good success using FST4W-1800 for non-line-of-sight optical scattering communication, spanning obstructed paths as long as 153 km by using LED arrays, Fresnel lenses, and photo-detectors.
Operators familiar with WSJT-X will find using FST4 and FST4W straightforward. Most on-screen controls, auto-sequencing, and other features behave as in other modes. Operating conventions on the LF and MF bands make it useful to have additional user controls to set the active frequency range used by the decoder. When File → Settings → General → Single decode is unchecked, spin boxes labeled F Low and F High set lower and upper frequency limits for the FST4 decoder.


The limits are marked by dark green angle-bracket symbols < > on the Wide Graph frequency scale:

If Single decode is checked the F Low and F High controls and green < > markers disappear, and decoding takes place only in the range RxFreq ± FTol.
For FST4W the default Rx Freq is 1500 Hz and F Tol is 100 Hz, so the active decoding range is the same as for WSPR, 1400 to 1600 Hz. However, you can select different center frequencies and F Tol values to conform with operating conventions on LF and MF bands.

A new drop-down control below F Tol offers a round-robin mode for scheduling FST4W transmissions:


If three operators agree in advance to select the options 1/3, 2/3, and 3/3, for example, their FST4W transmissions will occur in a fixed sequence with no two stations transmitting simultaneously. Sequence 1 is the first sequence after 00:00 UTC. For WSPR-like scheduling behavior, you should select Random with this control.
To see the presently suggested default FST4 and FST4W frequencies in the drop-down band-change control you must to do a one-time reset. Go to File → Settings → Frequencies, then right-click on the Working Frequencies table and select Reset.
Optional noise blanking is available and has been found effective in handling atmospheric noise on the LF and MF bands. A spinner control labeled NB nn % is located on the FST4 and FST4W main window, just below the band-change control. Set this control to a suggested percentage of data samples to be blanked. We have found that levels in the range 5 – 15% work well in summer conditions on LF/MF bands, but you will probably want to experiment. Data displayed on the waterfall and saved to .wav files do not have noise blanking applied, so you can experiment after the fact.
An experimental feature uses negative settings of NB to trigger a “try everything” approach to noise blanking: -1% causes the decoder to try 0, 5, 10, 15, and 20% blanking, and -2% tries 0, 2, 4, …, 20%. In FST4 mode the trials with nonzero blanking percentages are active only in the frequency range RxFreq ± FTol. Negative settings of NB can be very effective, but will slow the decoding procedure by significant amounts.
As an example of capabilities of the new modes, the screen shot on the next page shows FST4W-300 signals received on the 2200 m band at NO3M (locator EN91WR) on September 9, 2020. The distances involved are 3501 km to N6LF and 14,976 km to VK4YB. Numbers at the end of each decoded line are measured path Doppler spread in Hz. (To activate this feature, create a file named plotspec in the current working directory and start WSJT-X from the command line there.) As a general rule, decoding requires Doppler spreads less than the submode tone spacing. Sensitivity is best when Doppler spread is no more than 1/8 of the tone spacing.


Appendix A: Message Formats for FST4 and FST4W

Source encoding of FST4 messages is described in reference [1]. All messages are encoded into a 77-bit payload. To avoid transmitting a long string of zeros when sending CQ messages, the assembled 77-bit message is bitwise exclusive-OR’ed with the following pseudo- random sequence before computing the CRC and FEC parity bits:

01001010010111101000100110110100101100001000101001111001010101011011111000101

The receiving software applies this exclusive-OR procedure a second time, to restore the original 77-bit payload.
A 24-bit cyclic redundancy check (CRC) is calculated from and appended to each 77-bit information packet to create a 101-bit message-plus-CRC word. The CRC algorithm uses the polynomial 0x100065b (hexadecimal) and an initial value of zero.
Forward error correction is accomplished using a (240,101) LDPC code. The generator matrix has 139 rows and 101 columns. It is defined in the file generator_fst4.dat. Nonzero values in row i of the matrix specify which of the 101 message-plus-CRC bits must be summed, modulo 2, to produce the i

th parity-check bit. The 139 parity bits are appended to the 101 message-plus-CRC bits to create a 240-bit codeword.
Pairs of codeword bits are mapped to tone indices with values in the range 0 - 3 using the Gray encoding given in the third column of Table 3, in reference [1]. The resulting sequence of 120 channel symbols, an, n=0, 1, 2, …, 119 are divided into 4 groups:
MA={a0, a1, …, a29}
MB={a30, a31, …, a59}
MC={a60, a61, …, a89}
MD={a90, a91, …, a119}.
Synchronization is accomplished by embedding five 8-symbol synchronization words in the transmitted frame. The sync words are defined as follows:
S1={0, 1, 3, 2, 1, 0, 2, 3}
S2={2, 3, 1, 0, 3, 2, 0, 1}.
The complete set of 160 channel symbols is assembled as the sequence
bn = {S1, MA, S2, MB, S1, MC, S2, MD, S1}.

Source encoding of FST4W messages is described in reference [2]. All messages are encoded into a 50-bit payload. A 24-bit cyclic redundancy check (CRC) is calculated from and appended to each 50-bit information packet to create a 74-bit message-plus-CRC word. The CRC algorithm uses the polynomial 0x100065b (hexadecimal) and an initial value of zero.

Forward error correction is accomplished using a (240,74) LDPC code. The generator matrix has 166 rows and 74 columns. It is defined in the file generator_fst4w.dat. Nonzero values in row i of the matrix specify which of the 74 message-plus-CRC bits must be summed, modulo 2, to produce the ith parity-check bit. The 166 parity bits are appended to the 74 message-plus-CRC bits to create a 240-bit codeword.
The 240-bit codeword is mapped onto 160 channel symbols using the procedure described above for FST4.
References:
[1] Steve Franke, K9AN, Bill Somerville, G4WJS, Joe Taylor, K1JT “The FT4 and FT8 Communications Protocols,” QEX, July/August 2020, pp. 7-17.
[2] Steve Franke, K9AN, Bill Somerville, G4WJS, Joe Taylor, K1JT, in preparation.

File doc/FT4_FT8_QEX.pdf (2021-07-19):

QEX July/August 2020 7

extreme weak-signal performance on the VHF, UHF, and microwave bands. These modes use transmit and receive sequences of one minute, so two-way contacts generally require at least four minutes. By reducing the T/R sequences to just 15 seconds, optimizing the LDPC decoder in several important ways, and accepting a sensitivity loss (relative to JT65) around 4 dB, FT8 seems to have struck a sweet spot for DXing and general use on the HF, VHF, and lower UHF bands. FT4 accepts a further 3.2 dB loss in sensitivity but is twice as fast as FT8, and is potentially attractive for contesting at high QSO rates.
In this paper we provide full documentation of the FT4 and FT8 protocols and outline how the modes are implemented in WSJT-X. We present detailed performance measurements based on simulations over the additive white Gaussian noise (AWGN) channel and a range of standard International Telecommunications Union (ITU) models for HF propagation [12]. WSJT-X is an open source program licensed under version 3 of the Free Software Foundation’s General Public License (GPLv3). We provide some guidelines and a few restrictions on the use of our freely available source code by others.

### 2. Structured Messages and Source Encoding

FT4 and FT8 transmissions always convey exactly 77 bits of user information. Mappings between human-readable messages and the underlying information bits depend on designed-for-the-purpose compression techniques known as source encoding. The basic aim is to give the 77-bit information payload maximum utility for conveying the information necessary for basic station-to-station contacts. To facilitate efficient message compression for a range of targeted purposes, we allocate three bits to specify one of eight possible message types. The remaining 74 bits are for user information, with source-encoding details that depend on message type. Types are tagged with an integer variable that we call i3, and types that require fewer than 74 information bits can use the remaining bits to define subtypes tagged as i3.n3.
Table 1 presents a summary of
Steve Franke, K9AN | Bill Somerville, G4WJS | Joe Taylor, K1JT

# The FT4 and FT8 Communication Protocols

Motivation and design of the digital modes FT4 and FT8, and some details of how they are implemented in WSJT-X.

### 1. Introduction

FT4 and FT8 are digital protocols designed for rapid and accurate communication between amateur radio stations, particularly in weak-signal conditions. Information exchanged in a minimal two-station contact typically consists of call signs, four-character Maidenhead locators, signal reports, and acknowledgments. Special message formats support a few popular radio contests, and arbitrary text can also be conveyed, though only in small quantities. FT8 was introduced in July 2017 with version 1.8 of the software package WSJT-X [1, 2]. It quickly gained world-wide popularity, by some measures soon accounting for a large fraction of all ham radio activity on the high frequency (HF) bands [3]. FT4, a similar but faster protocol designed especially for radio contests, was introduced two years later in WSJT-X version 2.1.
The new protocols build on the legacies of JT4, JT9, JT65, and other digital modes pioneered in WSJT-X and its parent program WSJT, going back nearly 20 years [4-11]. These modes all use time-synchronized transmissions and structured messages with lossless compression of standard call signs, grid locators, and other basic information into a minimum number of bits. Strong forward error correction (FEC) is an integral part of each mode. FT8 and FT4 use a low density parity check (LDPC) block code designed and optimized specifi cally for this application.
Fundamental tenets of communication theory imply trade-offs involving message length, signaling rate, bandwidth, error-control coding, modulation type, decoding complexity, and minimum required signal-to-noise ratio (SNR). Earlier digital modes found
in WSJT-X, including JT4, JT65, and QRA64, were optimized for

Table 1 - Defi ned message types for the 77-bit payloads of FT4, FT8, and MSK144.

Type i3.n3 Purpose | Example message | Bit-fi eld tags
0.0 | Free Text | TNX BOB 73 GL | f71
0.1 | DXpedition | K1ABC RR73; W9XYZ <KH1/KH7Z> -08 c28 c28 h10 r5
0.3 | Field Day | K1ABC W9XYZ 6A WI | c28 c28 R1 n4 k3 S7
0.4 | Field Day | W9XYZ K1ABC R 17B EMA | c28 c28 R1 n4 k3 S7
0.5 | Telemetry | 123456789ABCDEF012 | t71
1. | Std Msg | K1ABC/R W9XYZ/R R EN37 | c28 r1 c28 r1 R1 g15
2. | EU VHF | G4ABC/P PA9XYZ JO22 | c28 p1 c28 p1 R1 g15
3. | RTTY RU | K1ABC W9XYZ 579 WI | t1 c28 c28 R1 r3 s13
4. | NonStd Call | <W9XYZ> PJ4/K1ABC RRR | h12 c58 h1 r2 c1
5. | EU VHF | <G4ABC> <PA9XYZ> R 570007 JO22DB h12 h22 R1 r3 s11 g25

3314 E. Anthony Dr., Urbana, IL 61802; k9an@arrl.net

Glendella, Wycombe Rd., Stokenchurch, High Wycombe HP14 3RP, England; g4wjs@classdesign.com

272 Hartley Ave., Princeton, NJ 08540; k1jt@arrl.net

Reprinted with permission; copyright ARRL.

### 8 QEX July/August 2020

all currently defi ned message types. Each type has a defi ned human-readable format that is mapped into a sequence of fi xed-length bit fi elds, each conveying specifi c information relevant to the type. Successive columns of Table 1 show for each message type the number i3 or i3.n3, the basic purpose, an example message, and a sequence of one or more bit-fi eld tags. Numbers in the tag names indicate the number of bits in that fi eld, and the total number of bits, including n3 (if used) and i3, is always 77.
Table 2 identifies the type of human-readable information conveyed by each distinct bit-field tag. The tags include ones to encode call signs, Maidenhead locators, signal reports, acknowledgments, various logical fl ags, and permissible exchanges for a few special operating activities such as VHF contests, ARRL RTTY Roundup, and ARRL Field Day.
Standard amateur call signs can be conveyed in 28 bits, but compound calls such as PJ4/K1ABC and special-event calls like YW18FIFA may require more than twice that number. To accommodate such special calls, message type 4 allows use of one arbitrary call sign with up to 11 alphanumeric characters. The other call sign in such messages is sent as a hash code of just 12 bits. Such a mapping from call sign to hash code is uniquely defi ned, but obviously the inverse mapping cannot be unique. When the WSJT-X receiving software fi nds a message containing a hash code it displays the most recently decoded call sign mapping to that code (or perhaps “mycall”, if it maps to that code), enclosed in angle brackets: for example <PJ4/K1ABC>. If no call sign is available for the received hash, the missing information is displayed to the user as <...>. Different message types may use different hash code lengths. For example, message type 0.1 always sends the transmitting station’s call sign as a 10-bit hash code, and message type 1 conveys any call enclosed in angle brackets as a 22-bit hash code. Hash code “collisions” are possible, of course, but in practice we fi nd they are rare. Further low-level details of these and other source encoding algorithms, including ranges of permitted values, can be found in Appendix A.

### 3. Error Detection and Error Correction

A 14-bit cyclic redundancy check (CRC) is appended to each 77-bit information packet to create a 91-bit message-plus-CRC word. The CRC is calculated on the source-encoded message, zero-extended from 77 to 82 bits. The CRC algorithm uses the polynomial 0x6757 (hexadecimal) and an initial value of zero (see [13, 14] for further details). Another 83 bits are appended for forward error correction, creating a 174-bit codeword.
Forward error correction is accomplished using a (174, 91) LDPC code designed specifi cally for FT8 and FT4. The code is defi ned by two matrices: a generator matrix used to compute the 83 parity bits appended to each 91-bit message-plus-CRC word, and a parity matrix that can be used to determine if a given 174-bit

### sequence is a valid codeword. All values in both matrices are either

0 or 1, and their related operations use modulo 2 binary arithmetic.
The generator matrix has 83 rows and 91 columns. It is defi ned in a fi le generator.dat and included along with a number of other useful fi les in reference [14]. Nonzero values in row i of the matrix specify which of the 91 message-plus-CRC bits must be summed, modulo 2, to produce the i

th parity-check bit. Similarly, a file parity.dat [14] defi nes the sparse 83 × 174 parity-check matrix. The locations of the 1s in each row of this matrix specify which bits of a 174-bit codeword must sum (modulo 2) to zero. The 174-bit word is a valid codeword only if all 83 sums are zero.

### 4. Channel Symbols and Modulation

FT8 messages are transmitted using 8-tone continuous-phase frequency shift keying (CPFSK). Each transmitted tone or channel symbol conveys three bits. The sequence of 174 codeword bits is mapped onto a sequence of 174/3 = 58 channel symbols an, with n running from 0 to 57. The value of each symbol corresponds to a tone index in the range 0 to 7. Groups of three consecutive message bits are mapped to channel symbols using a Gray code defi ned by columns 1 and 2 of Table 3. This mapping ensures that bit triads associated with adjacent tones differ in only one bit position, thereby improving decoding performance on channels where Doppler spread is comparable to the tone separation.
FT4 is similar but uses 4-tone CPFSK, so each channel symbol conveys only two message bits. The sequence of 174 codeword bits is mapped onto a sequence of 174/2 = 87 channel symbols an, n = 0, 1, 2, ..., 86, with each symbol value an integer tone index in the range 0 – 3. Pairs of successive message bits are mapped to channel symbols according to the Gray code defi ned by columns 1 and 3 of Table 3.

Tone patterns known as Costas arrays are embedded in FT8 and FT4 waveforms to allow the receiving software to synchronize properly with received signals in both time and frequency. For FT8 we use the seven-tone sequence 3, 1, 4, 0, 6, 5, 2 inserted at the beginning, middle, and end of the transmitted waveform. If

Table 2 - Assigned purposes for the bit fi elds listed in Table 1. Numbers in the tags indicate the number of bits in that fi eld.

Tag | Information conveyed
c1 | First callsign is CQ; h12 is ignored
c28 | Standard callsign, CQ, DE, QRZ, or 22-bit hash
c58 | Nonstandard callsign, up to 11 characters
f71 | Free text, up to 13 characters
g15 | 4-character grid, Report, RRR, RR73, 73, or blank
g25 | 6-character grid
h1 | Hashed callsign is the second callsign
h10 | Hashed callsign, 10 bits
h12 | Hashed callsign, 12 bits
h22 | Hashed callsign, 22 bits
k3 | Field Day Class: A, B, ... F
n4 | Number of transmitters: 1-16, 17-32
p1 | Callsign suffi x /P
r1 | Callsign suffi x /R
r2 | RRR, RR73, 73, or blank
r3 | Report: 2-9, displayed as 529 – 599 or 52 - 59
R1 | R
r5 | Report: -30 to +32, even numbers only
s11 | Serial number (0-2047)
s13 | Serial Number (0-7999) or State/Province
S7 | ARRL/RAC Section
t1 | TU;
t71 | Telemetry data, up to 18 hexadecimal digits

Table 3 - Bi-directional Gray mapping between message bits and channel symbols.

Channel Symbol | FT8 Bits | FT4 Bits
0 | 000 | 00
1 | 001 | 01
2 | 011 | 11
3 | 010 | 10
4 | 110
5 | 100
6 | 101
7 | 111

rate, usually measured in bauds.) The frequency deviation pulse is normalized to have unit area,
p t dt () 1,

∞

-∞

= ò | (2)

so the pulse weighted by symbol bn causes the carrier phase to advance by 2πhbn radians over the duration of the pulse. For WSJT-X modes other than FT4 and FT8, p(t) is a rectangular pulse with duration T and peak amplitude 1/T. For these modes the instantaneous frequency deviation of the nth pulse is hbn/T.
The pulse amplitudes, bn, are integers in the range 0 – 7 for FT8 and 0 – 3 for FT4. With this convention the carrier frequency fc is the lowest tone frequency, i.e., the frequency transmitted during an interval with bn = 0. The occupied bandwidth and spectral shape of the CPFSK signal depend on the modulation index, h, the signaling interval T, and the shape of the frequency deviation pulse p(t). These parameters are summarized in Table 4, where for comparison we include, in addition to FT4 and FT8, several other modes supported in WSJT-X. The modes JT4, JT9, JT65, and MSK144 use rectangular frequency-deviation pulses, so their frequency deviations fd have discontinuous jumps when bn changes from one signaling interval to the next. Such jumps create relatively large spectral sidelobes in the CPFSK signal. In FT4 and FT8 the sidelobes are minimized by smoothing the frequency deviation function fd(t) with a Gaussian filter. Waveforms generated in this way are called Gaussian Frequency Shift Keyed (GFSK) signals.
Smoothing the frequency deviation waveform directly would require a numerical convolution every time a new message is generated. It is computationally more effi cient to apply the Gaussian smoothing fi lter to an isolated rectangular pulse, which needs to be done only once. The Gaussian-smoothed pulses can then be superposed according to Equation (1) to obtain the GFSK frequency deviation waveform. Such waveforms are equivalent to those obtained by fi rst generating the FSK waveform with rectangular pulses and then convolving it with a Gaussian smoothing function. The GFSK Gaussian-smoothed pulse satisfying the normalization condition (2) can be written in terms of the error function, erf(x), as
() 1 erf | 0.5 | erf | 0.5 | .
2
t | t p t | kBT | kBT T | T | T
é | ù æ | ö | æ | ö æ | ö | æ | ö = | + | - | - ê | ú ç | ÷ | ç | ÷ ç | ÷ | ç | ÷ ë | û è | ø | è | ø è | ø | è | ø
(3)
Here the constant k = | = π 2 / ln 2 5.336..., and B is the smoothing
fi lter’s -3 dB bandwidth. The error function erf(x) is defi ned as
() 2

0

2 erf | .

x
t x | e dt π
- = | ò

A Gaussian smoothing fi lter has a low-pass frequency response with Gaussian shape. For FT8 we set the -3 dB bandwidth to B = 2T⁻¹, or BT = 2. FT4 uses a more heavily smoothed pulse with

Table 4 - Parameters of the CPFSK signals used for six modes in WSJT-X. Pulse amplitudes assume integer values over the specifi ed ranges.

Mode | T(s) | Modulation index, h | Pulse shape, p(t) | Pulse amplitude, bn
FT4 | 0.048 | 1 | Gaussian-smoothed, BT=1 | 0 – 3
FT8 | 0.160 | 1 | Gaussian-smoothed, BT=2 | 0 – 7
JT4 | 0.2286 | 1 | Rectangular | 0 – 3
JT9 | 0.5760 | 1 | Rectangular | 0 – 8
JT65 | 0.3715 | 1 | Rectangular | 0, 2 – 65
MSK144 | 0.0005 | 0.5 | Rectangular | 0 – 1

### the sync sequence is denoted S and the fi rst and second halves

of the information symbols by | { | } 0 | 1 | 28 , ,..., M | aa | a A = | , and
{ | } 29 | 30 | 57 , ,...., M | aa | a B = | , the complete set of 79 transmitted symbols
can be written as the sequence | { | } , | ,, | , n | A | B b | SM SM S = | . Synchronization in FT4 uses four different Costas arrays, defi ned

as follows:
S1 = { | | | | | | | | } 0,1,3,2 ,
S2 = { | } 1,0,2,3 ,
S3 = { | } 2,3,1,0 ,
S4 = { | } 3,2,0,1 ,

### FT4 transmissions contain 87 information-carrying symbols. We divide these into three groups of 29:

{ | } 0 | 1 | 28 , ,..., | , M | aa | a A =
{ | } 29 | 30 | 57 , ,..., | , M | aa | a B =
{ | } 58 | 59 | 86 , ,..., | . M | aa | a C =

### To minimize keying transients we add a special ramp symbol R with tone index 0 that establishes slow transitions from zero

amplitude at the start and to zero at the end of each waveform.

### A complete set of 105 channel symbols is then assembled as the sequence of values

{ | } 1 | 2 | 3 | 4 ,, | ,, | ,, | ,, . n | A | B | C b | RS M S M S M S R =

### 5. Generated Waveforms

Both protocols use continuous-phase frequency shift keying, which implies generated waveforms of the form
() | cos 2( | ) () . c s t | A | ft | t = | + π | φ

Here A is signal amplitude, fc is carrier frequency, t is time, and φ(t) is phase. The phase term can be written as the integral of instantaneous frequency deviation, fd(t),
() | ( ) 0
2 | , | 0.

t
d φ | π | ττ t | f | d | t = | ≥ ò

This scheme guarantees that φ(t) is continuous, even across discontinuous steps in fd. Signal amplitude A is constant, except for enforced rise and fall times at the start and end of a transmission. This constant-amplitude or constant envelope feature ensures that nonlinear amplification of the signal will not generate intermodulation products.
Frequency deviation fd(t) is evaluated as the weighted sum of a sequence of pulses, p(t):
() | ( | ). d | n

n

f t | h b p t nT = | - ∑ | (1)

Here h is called the modulation index, weights bn are the channel symbol values, p(t) is the frequency deviation pulse shape, and T the signaling interval. (Note that T is the inverse of the keying


### 10 QEX July/August 2020

BT = 1. In the limit of very large fi lter bandwidth, BT 1, the pulse shape p(t) defi ned by Equation (3) becomes rectangular and equivalent to the pulse used to generate standard FSK as in the older WSJT modes. The frequency deviation pulses actually used in WSJT-X are plotted for comparison in Figure 1.
Duration of the smoothed FT4 and FT8 pulses is greater than the signaling interval T, so successive pulses overlap. This intersymbol interference (ISI) is introduced deliberately for the purpose of shaping the emitted spectrum to reduce sidelobe levels. For the values of BT used in FT4 and FT8, signifi cant ISI is present only between immediately adjacent pulses. Thus, when summing pulses to produce fd(t) using Equation (1), at time t it is only necessary to include contributions from the pulse whose center is closest to t and those immediately before and after it.

Figure 2 shows a portion of an FT4 frequency deviation waveform fd(t). It’s easy to see that corners of the waveform at symbol boundaries have been rounded. As an example to illustrate the reduc-tion in spectral sidelobes eff ected by using GFSK, Figure 3 shows the spectrum of an FT4 signal and one generated using standard FSK with no smoothing. The diff erence in sidelobe levels is striking. The

### compact spectra of FT4 and FT8 signals make it possible for dozens of them to occupy a spectral slice of a few kHz, with little or no inter-

signal interference.
FT4 and FT8 waveforms have constant amplitude except at the very beginning and end of a transmission. FT8 signals are ramped up gradually over a transition interval T/8, or 20 ms, at the beginning of the fi rst sync symbol. The ramp function is a raised cosine,
At | t T | t T () = | - 0.5 1[ cos (8 / ], | 0 | / 8. π ) | ≤ ≤

Figure 4 illustrates the FT8 ramp function and the leading part of an FT8 waveform. The same taper is used in reverse to gradually ramp down the signal at the end of the transmission. FT4 waveforms are similarly soft-keyed, this time using raised-cosine tapers applied over the full 48 ms duration of the special ramping symbols R, described earlier.

### 6. Symbol Detection and Decoding

Sections 2 through 5, Appendix A, and resources in reference
[14] define the source encoding, error-correction coding, and modulation scheme associated with the FT4 and FT8 protocols. Any proper implementation of these protocols should strictly adhere to these defi nitions. In this section we turn to a discussion of some implementation-specifi c methods used in WSJT-X for detecting

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
3 | 3.2 | 3.4 | 3.6 | 3.8 | 4

Frequency Deviation (Hz)

Time (s)

Frequency (Hz); FSK

Figure 1 — Gaussian-smoothed frequency deviation pulses. The pulses labeled BT=1 and BT=2 are used to generate the FT4 and FT8 frequency-deviation waveforms, respectively. The case BT=99 is essentially the same as the unfi ltered rectangular pulse that is used to generate standard, unsmoothed FSK in JT65, JT9, and other modes in WSJT-X.

Figure 2 — A segment of an FT4 frequency deviation waveform generated using the Gaussian-smoothed frequency deviation pulse with BT=1.0.

Amplitude

500 505 510 515 520 525 530 535 540 t (ms)

Figure 4 — The beginning of an FT8 waveform showing gradual rise of the signal envelope over the fi rst 20 ms. FT4 uses a similar raised-cosine ramp expanded to 48 ms duration. Time-reversed ramp-down functions are used at the ends of transmissions.

Figure 3 — Average spectrum of an FT4 signal (GFSK, BT=1.0: dotted line) and the spectrum of an otherwise equivalent standard FSK waveform (solid line).

and decoding FT4 and FT8 signals. Other approaches are certainly possible, and might be used by other software developers.
WSJT-X uses advanced detection and decoding techniques to decode the weakest possible signals. Noncoherent block detection over sequences of two or more channel symbols improves sensitivity over single-symbol detection when the received signal maintains phase coherence over multiple symbols [15]. Single-symbol detection provides robust detection on rapidly fading channels, while longer block lengths provide better sensitivity in slow fading conditions. We use block lengths of N = 1, 2, and 3 symbols for FT8, and N = 1, 2, and 4 for FT4.
Block detection is carried out by correlating received waveform segments spanning N symbols with locally generated waveforms corresponding to each of M N possible symbol sequences. Here M is the number of different modulation waveforms (tones) used for each mode, M = 8 for FT8 and M = 4 for FT4. For this technique to provide sensitivity gains the received signal must be phase-stable over the block length. Such detection is said to be noncoherent, however, because phase continuity between sequences is not assumed. Only the magnitude of the complex-valued correlation is used, and detection is independent of phase differences between the received signal and locally generated waveforms. Output from the block detector is a set of M N positive real correlation values. These are used to derive soft decisions for each of the N log2 M bits conveyed by the N- symbol sequence.
Conversion of the waveform correlations to soft decisions is accomplished using a soft demapper. The soft metric Lj
for xj

, the j

th
bit associated with a particular symbol sequence, can be written as
:x 1 | :x 0
max | max | , j | j
j | i | i i | i
L | K | C | C = | =
æ | ö = | - ç | ÷ è | ø
where : | 1
max j = | i ix
C | is the largest correlation magnitude from the set

of MN/2 correlations between the received waveform and ideal waveforms associated with bit sequences having xj
= 1. Likewise, the
second term is the largest magnitude from the other half of the set of correlations, associated with xj
= 0. The normalization constant, K, is adjusted empirically to optimize performance over a range of SNRs and channel conditions. For example, consider block detection of sequences of N = 3 successive FT8 symbols. Since each symbol could have any one of M = 8 values, there are 8³
= 512 possible
three-symbol waveforms to be correlated with each three-symbol block of the received waveform. The resulting 512 correlation values determine soft decisions for the 9 bits conveyed by the sequence. In practice, WSJT-X calculates the 8 correlations required for single-symbol (N = 1) detection fi rst, using a fast Fourier transform. The single-symbol complex results are then combined to produce the 64 correlations required for N = 2 and the 512 correlations required for N = 3 block detection, thereby avoiding needless redundant calculations.

A set of 174 soft decisions is obtained for each block size. These are submitted to the decoder, starting with the set for N = 1. If the decoder returns a codeword whose 77-bit message produces a 14-bit CRC that matches the decoded CRC, the algorithm terminates and the decoded message is unpacked and displayed to the user.
Our decoder uses a hybrid approach that combines the fast, iterative, belief propagation (BP) algorithm [16] with the more sensitive but computationally expensive ordered statistics decoding (OSD) algorithm [16]. In practice we fi nd that most received signals are decoded with just a few iterations of the BP algorithm. When BP fails to fi nd a valid codeword after a reasonable number of iterations, the soft decisions are submitted to the OSD algorithm. The OSD algorithm can provide several dB of additional sensitivity under certain conditions. Our implementation of the OSD algorithm incorporates the preprocessing rules from reference [17]. We found that these shortcuts signifi cantly improve the computational effi ciency of the OSD approach.
Our decoders can optionally make use of so-called a priori (AP) information as it accumulates during a QSO. For example, when you answer a CQ you already know your own call sign, that of your potential QSO partner, and the type of message you expect to receive if your reply is successful. Your decoding software therefore “knows” what might be expected for at least 62 message bits (29 for each of two call signs and /R fl ags, 1 for the R indicator, 3 for message type) in the next received message. With these bits hypothesized as a conjecture, the decoder’s task can be reduced to determining the remaining 15 bits of the message and ensuring that the resulting solution is reliable. The use of AP information can increase sensitivity by several dB at the cost of a somewhat higher rate of false decodes.
Table 5 shows measured decoding thresholds for FT4 and FT8 derived from simulations, providing insight into the sensitivity gains offered by block detection and OSD. Here and elsewhere in this paper, quoted sensitivity thresholds are the signal-to-noise ratios in 2500 Hz bandwidth at which decoding probability is 0.5. Numbers in the fi rst table row for each mode represent a baseline case with single-symbol N = 1 detection and BP decoding. The next two rows add block detection and block detection with hybrid (BP and OSD) decoding. Column 2 gives results for the non-fading additive white Gaussian noise (AWGN) channel, while columns 3 and 4 are for channels with frequency spreads of 1 Hz and 10 Hz, respectively. See Section 8 for more information about the channel models. One can see that on the AWGN channel block detection improves sensitivity by 1.6 dB and 0.7 dB for FT4 and FT8, respectively. Addition of hybrid decoding provides another 0.6 dB and 0.5 dB. Overall, block detection and the hybrid decoder offer 2.2 and 1.2 dB of sensitivity improvement over the baseline case for FT4 and FT8, respectively. On the mid-latitude disturbed channel, block detection improves sensitivity by 1.3 dB and 0.5 dB, and overall improvements are 2.5

Table 5 - Decoding thresholds for three different channels and three decoding schemes.

Decoding Algorithm | AWGN (dB) | Mid-latitude Disturbed (dB) | High-Latitude Moderate (dB)

FT4:
N=1; BP | –15.3 | –12.7 | –10.4
N=1,2,4; BP | –16.9 | –14.0 | –10.5
N=1,2,4; BP+OSD | –17.5 | –15.2 | –12.2

FT8:
N=1; BP | –19.6 | –16.5 | -
N=1,2,3; BP | –20.3 | –17.0 | -
N=1,2,3; BP+OSD | –20.8 | –18.6 | –8.6

### 12 QEX July/August 2020

and 2.1 dB. Doppler spread on the high-latitude disturbed channel exceeds the FT8 tone spacing, and FT8 fails to achieve a 50% decode probability at any SNR using only the baseline decoding scheme. With its larger tone spacing FT4 outperforms FT8 on this channel. Block detection does not offer signifi cant improvement in this case — only 0.1 dB for FT4 — because coherence time on this rapidly fading channel is comparable to or smaller than the durations of the multi-symbol blocks.
After a signal is decoded we have the information necessary to regenerate the waveform that was actually transmitted. We use the regenerated signal as a reference to derive the time-varying, complex gain function that describes the effect of the propagation channel. Denote the real received audio signal by s(t) and defi ne a complex reference signal by
() () ( | ) 2 0 | () , j | ft | t rt | Ate π | φ+ =

where f0 is the estimated audio frequency of the decoded signal and A(t) and φ(t) are the amplitude and phase of the transmitted waveform. The time-varying complex channel gain function, g(t), is obtained via:
() | () () * g t | LPF s t r t = | é | ù, ë | û

where LPF[ ] represents a low-pass fi lter and * represents the complex conjugate. The low-pass fi lter cutoff is optimized for best performance with real signals received under a range of different propagation conditions. The estimated channel gain function is applied to the ideal reference signal to reconstruct a nearly noiseless version of the received signal’s waveform, including channel-induced amplitude fading and phase variation. The reconstructed signal is then subtracted from the received data, i.e.
s t | st | gtrt ′() () | () () = | - 2 é | ù R ë | û

where R[] takes the real part of its argument, and s’(t) is the audio waveform after subtracting the decoded signal. This subtraction process can uncover weaker signals that occupy the same frequency slot as the subtracted strong signal. The weaker signals can often be decoded on a second decoding pass, after all signals decoded in the fi rst pass have been subtracted.
WSJT-X analyzes an audio waveform that may contain many signals in the received passband. A decoding pass starts by identifying all likely signals, or candidates, using spectral analysis. Then, for each candidate in succession, our procedure is to (1) synchronize, estimating the frequency offset from the upper-sideband dial frequency and the time offset with respect to the computer’s system clock; (2) determine soft decisions for each of three block lengths and attempt to decode each one using either BP alone or BP+OSD; (3) if the decode is successful, subtract the signal. If at least one signal is decoded and subtracted in the fi rst decoding pass, the remaining audio waveform is re-analyzed. New candidates are identifi ed and steps 1 through 3 are carried out for each one. If at least one new signal is decoded and subtracted in the second pass, a third pass will sometimes yield decodes missed in the fi rst two passes. Multi-pass decoding has proven very effective: the approach is often able to decode two or three signals at the same or nearly the same frequency.

### 7. Message Sequencing

A basic QSO between K1JT and K9AN might consist of the following messages:

### Tx6: CQ K1JT FN20 Tx1: K1JT K9AN EN50 Tx2: K9AN K1JT -10 Tx3: K1JT K9AN R-12 Tx4: K9AN K1JT RRR Tx5: K1JT K9AN 73

Here the Txn: labels are those used to identify message entry fields on the WSJT-X user interface. In this model QSO even-numbered messages are sent by K1JT, odd-numbered messages (those displaced to the right) by K9AN. Note that all messages bear the transmitting station’s call sign, and all but the CQ are explicitly directed to a particular QSO partner. Most QSOs follow the sequence shown, or a closely related one depending on context, propagation, and interference conditions. In normal usage, failure to decode a response from a QSO partner implies repetition of the previous transmission.
Traditionally, operators have clicked buttons on the user interface (UI) of WSJT-X [1, 2, 19] and its predecessor WSJT [4-11] to trigger transmission of the next message in a sequence similar to that shown above. Protocols with one-minute T/R sequences leave about 10 seconds between decoding and start of the next transmission, so there is plenty of time to decide upon and activate one’s next transmission. However, the shorter sequences of FT8 and FT4 require much quicker responses, effectively requiring moderate amounts of automation built into the software.
If a UI checkbox labeled Auto Seq has been ticked, the software parses decoded messages to decide whether a valid response for the standard QSO sequence has been received, directed to “mycall”. If so, the next message in the sequence is queued and transmitted; if not, the previous transmission is repeated. This sequence of events proceeds until a QSO is completed or abandoned by user action. With a few optional exceptions (“Fox” operation in FT8 DXpedition mode, and contest operation), user action is also required to verify QSO details and submit them for logging. In any event, by design WSJT-X requires that every QSO must be initiated by a human operator. We do not like the idea of fully robotic operation with modes like FT4 and FT8, and the WSJT-X software prevents it. These moderate levels of automation involve considerably more logic in the software, essentially duplicating the thought processes of an attentive user progressing through a valid QSO. In typical operation on a busy HF or VHF band, dozens of valid FT4 or FT8 messages may be decoded in a single receiving sequence. The receiving software must analyze all of these, determine whether any is a valid reply in the expected sequence for a QSO already underway, and take appropriate action. Figure 5 provides a high-level summary of the six major states of the WSJT-X auto-sequencing behavior. On program startup, and when Halt Tx is clicked, the logical state machine is put into the Calling state. Subsequent stages of a standard

Acronyms and abbreviations used in text.

AP | a priori, as in AP decoding
AWGN | additive white Gaussian noise
BP | belief propagation
CPFSK | continuous-phase frequency-shift keying
CRC | cyclic redundancy check
FEC | forward error correction
GFSK | Gaussian frequency-shift keying
GPLv3 | General Public License, version 3
ISI | inter-symbol interference
ITU | International Telecommunication Union
LDPC | low-density parity check code
MinGW | Minimalist GNU for Windows
OSD | ordered statistics decoding
SNR | signal-to-noise ratio
UI | user interface

Sequencing; Halt Tx; Replying; Report; Signoff; Rogers; Roger Report; Calling

Figure 5 — Top-level state diagram for standard message sequencing in WSJT-X.

Calling; for us; yes; message decoded [auto sequencing armed && Call 1st]; decode double-clicked; no more decodes; Waiting; / Tx message = Tx6 [AutoSeq] / arm auto sequencing; Parse message; do / disarm auto sequencing do / extract DX call & grid do / generate Tx messages; skip Tx1; [message == Tx6]; Tx message == Tx6; [message == Tx1] / Tx message = Tx2; [message == Tx2] / Tx message = Tx3; [message == Tx4] / Tx message = Tx5; / Tx message = Tx1; / Tx message = Tx2; [message == Tx3] / Tx message = Tx4

Figure 6 — Example detailed state chart for the high-level “Calling” state shown in Figure 5.

QSO pass through the Replying, Report, Roger_Report, Rogers, and Signoff states while proceeding through the sequence of transmitted and received messages illustrated at the start of this section.
Each major state has its own internal logic that determines what action will be taken when specifi ed types of messages are received. An idealized and abbreviated representation of this logic for the Calling state is presented in Figure 6. Here and in Figure 5 we have used Unifi ed Modeling Language notation [18], which should be mostly self-explanatory. For example, the text

[message == Tx1] / Tx message = Tx2

attached to a state transition line has the form “trigger [guard condition] / action,” so this is a transition that happens automatically without any triggering event, but only if the just parsed message has the standard Tx1 format. In this case the transition has a side effect of setting the next message queued for transmission as the generated Tx2 message.
The user interface provides options for configuring various details of the auto-sequencing behavior; please consult the WSJT-X 2.1 User Guide [19] for further details.

Decode Probability; SNR 2500 (dB); FT8 AWGN; FT4 AWGN; FT8 Mid disturbed; FT4 Mid disturbed; FT8 High moderate; FT4 High moderate

### 14 QEX July/August 2020

### 8. Performance Measurements

While designing FT4 and FT8 we used channel simulations based on the approach recommended by the ITU [12] to assess the performance that could be achieved under real-world conditions. The channel model assumes two independently fading paths with equal mean attenuation and equal frequency spreads. A channel is defined by its frequency spread and differential path delay. Reference [12] specifi es frequency spread and path delay parameters for quiet, moderately disturbed, and highly disturbed conditions in low-latitude, mid-latitude, and high-latitude terrestrial regions. The ITU channels referenced in this paper have differential path delays that are small compared to FT4 and FT8 symbol durations, so this parameter has little effect on performance. The size of a channel’s frequency spread relative to the tone spacing of the mode is the most important factor determining the extent of performance degradation. Figure 7 compares FT4 and FT8 performance obtained using WSJT-X version 2.1 to decode simulated FT4 and FT8 waveforms under non-fading additive white noise (AWGN) conditions, and on mid-latitude disturbed and high-latitude moderately disturbed channels. Table 6 lists the channel parameters and the decoding threshold for these channels along with the mid-latitude quiet and mid-latitude moderate channels. FT8 maintains about 3 dB sensitivity advantage over FT4 on AWGN and mid-latitude channels where frequency spread is smaller than the tone spacing for both modes. Frequency spread on the high-latitude channel is larger than the FT8 tone spacing and smaller than FT4’s tone spacing, which explains why FT4 performs best in that case.
Table 6 includes decoding thresholds obtained when the maximum possible amount of AP information is available. Maximum AP information provides about 2 dB of additional sensitivity on less disturbed channels and increasing improvement as frequency spread increases. On the most disturbed channel, large improvements of about 5 dB and 10 dB are obtained for FT4 and FT8, respectively. The trend is similar for scenarios where less AP information is available.
Figure 8 provides a detailed look at how using AP information can improve sensitivity as a QSO progresses. The mid-latitude disturbed channel was used for this set of simulations. The curve labeled “no AP” is the same as the curve labeled “FT8 Mid disturbed” Figure 7. The curve labeled “caller” shows sensitivity to responses to a CQ, or any other message directed to “mycall”. The curve labeled “report” indicates sensitivity to messages directed to “mycall”, originating from the known call sign of a QSO partner. This curve represents the sensitivity to a report or roger-report message during a QSO. Finally, the curve labeled “RRR/RR73/73” represents sensitivity to an RRR, RR73, or 73 message from a QSO partner, at the end of a QSO.
Figure 8 shows a modest sensitivity improvement to a caller when only “mycall” is used as AP information. The advantages of such AP information become more signifi cant when the caller fails to start transmitting at the nominal start time, 0.5 s after the

Table 6 - FT4 and FT8 decoding thresholds measured using simulations. In all cases, the decoder used block detection and (BP+OSD). For each channel and mode, two decoding thresholds are given. “No AP” is the threshold when no a priori information is available, and “max. AP” is the decoding threshold with the maximum amount of a priori information, at the end of a QSO when receiving RRR, 73, or RR73 from a QSO partner.

Channel | Frequency | Diff. Path | FT4 Decoding | FT4 Decoding | FT8 Decoding | FT8 Decoding
| Spread (Hz) | Delay (ms) | Threshold (dB), | Threshold (dB), | Threshold (dB), | Threshold (dB),
| | | no AP | max. AP | no AP | max. AP
AWGN | 0.0 | 0.0 | –17.5 | –19.5 | –20.8 | –22.7
Mid-latitude quiet | 0.1 | 0.5 | –17.4 | –19.4 | –20.0 | –22.4
Mid-latitude moderate | 0.5 | 1.0 | –15.8 | –18.6 | –18.8 | –22.1
Mid-latitude disturbed | 1.0 | 2.0 | –15.2 | –18.4 | –18.6 | –22.1
High-latitude moderate | 10.0 | 3.0 | –12.2 | –17.4 | –8.6 | –18.9

Figure 7 — Measured decoding probability as a function of SNR for FT8 and FT4, based on simulations for three propagation channels: additive white Gaussian noise (AWGN), and the ITU standards for mid-latitude disturbed and high-latitude moderate conditions. No AP information was used for these sensitivity measurements.

beginning of a transmit interval. In such cases, WSJT-X will skip the missed part of the transmission and start sending a correctly synchronized message for the remainder. Those receiving such a truncated message will collect only a fraction of the message symbols. A common scenario for this occurrence is “late” responses to a CQ. For example, suppose that G4WJS calls CQ. He knows that responses to his call will be addressed to G4WJS. The “no AP” curve in Figure 9 shows that without the use of AP information, responses from callers who start transmitting more than 5 seconds after the beginning of a Tx interval will not be decoded. The curve labeled “AP mycall” shows decoding probability as a function of start time when the decoder specifi cally looks for responses directed to G4WJS. In this case transmissions that were started up to 8 seconds late are likely to be decoded successfully.

### 9. Concluding Remarks and Software License

This paper and the online resources found in reference [14] provide complete descriptions of the FT4 and FT8 protocols. In the spirit of open sharing, and to encourage other software developers who might use some of our ideas, we place this description in the public domain with the following restrictions:
- Other software implementers may use the names “FT4” and “FT8” only if they adhere to our protocol defi nitions for source encoding, error-correction coding, and modulation format.
- Robotic or unattended QSOs must be explicitly disallowed.
- Multi-streaming with waveforms and message content similar to those used in FT8 DXpedition Mode is permissible only within the guidelines specifi ed in the WSJT-X 2.1 User Guide [19].
- Presently unassigned message types (see Table 1) are reserved for future expansion and must not be assigned without our permission.
- Any implementation of these or similar protocols that allows robotic, unattended, or non-conforming multi-streaming operation shall not use the names “FT4” or “FT8” and must be made incompatible by some means, such as using different Costas arrays for synchronization.

Decode Probability; SNR 2500 (dB); caller; report; RRR/ RR73/73

With the exception of code contained in reference [14], source code for our implementations of FT4, FT8, and MSK144 is not in the public domain. Rather, all code in WSJT-X is copyrighted and licensed under the terms of Version 3 of the GNU General Public License (GPLv3), reference [20]. Very briefly stated, GPLv3 guarantees end users the freedom to run, study, and modify the software, so long as the same licensing terms are extended to any new software derived from or dependent upon our source code. We welcome any independent software implementations of FT4 and FT8, so long as they either (1) adhere to all requirements mentioned above, or (2) make no use of our source code beyond the public-domain resources mentioned above. We hope and trust that many of the innovations pioneered in WSJT-X and its predecessors will outlive its present developers — and will continue to advance the art of weak-signal communication by Amateur Radio for many years to come.

Appendix A. Source Encoding Details
Section 2 of this paper is a summary of how the FT4, FT8, and MSK144 protocols pioneered in WSJT-X compress and convey call signs, Maidenhead locators, signal reports, and certain other information in a very effi cient way. Tables 1 and 2 outline the basic source-encoding framework, with each message payload comprising a sequence of fixed-length bit fields. This Appendix completes the details needed to fully defi ne mappings from human-readable message fragments to relevant fi elds in the fi xed-size 77-bit message payload. For the convenience of others who might wish to implement the FT4 or FT8 protocols, some essential algorithmic parts of the defi nitions are presented in simple, very short Fortran programs whose source code we have placed in the public domain [14].
As fi rst steps we shall defi ne the way standard call signs and 4-character Maidenhead locators are encoded into fi elds of just 28 and 15 bits, respectively. As described in the WSJT-X 2.1 User Guide [19], a standard amateur call sign consists of a one- or two-character prefi x, at least one of which must be a letter, followed by a decimal digit and a suffi x of up to three letters. Within these rules, the number of possible call signs is equal to 37×36×10×27×27×27 =

SNR -10dB; Decode Probability; Delay to TX Enable (s); AP mycall

Figure 9 — Decode probability for FT8 when the transmitting station starts transmitting after the beginning of a 15 s interval. The simulation was performed for the mid-latitude moderately disturbed channel, at SNR = –10 dB. The kink in the “AP mycall” curve at 6.5 s arises because missing symbols from the Costas array in the middle of the FT8 transmission have little effect on decoding probability.

Figure 8 — Decode probability for FT8 on the mid-latitude disturbed channel using different amounts of a priori (AP) information. See text for details.

### 16 QEX July/August 2020

262,177,560. (The numbers 27 and 37 arise because in the fi rst and last three positions a character may be absent, or a letter, or perhaps a digit.) Since 2²⁸ = 268,435,456 is a larger number, 28 bits are enough to encode any standard call sign uniquely, while leaving 6,257,896 values available for conveying other types of information. A few of these excess values are assigned to special message components such as DE, QRZ, and CQ (optionally with a modifi er). A further 2²² = 4,194,304 are used to convey 22-bit hash codes for call signs. Similarly, there are 180×180 = 32,400 four-digit Maidenhead grid locators. This number is less than 2¹⁵ = 32,768, so a grid locator can be uniquely represented in 15 bits. Some of the 368 fi fteen-bit values not needed for grid locators are used to convey numerical signal reports of the form ±nn in the range -30 to +99 dB, or a blank, or one of the words RRR, RR73, or 73.
As a particular example, consider the bit allocations for message type 1, an essential part of almost all FT4 and FT8 QSOs. These basic messages usually contain two 28-bit call signs, an optional acknowledgment R, and a four-character locator, signal report, RRR, RR73, or 73. Table 1 shows that this message type consists of fi elds with the tags c28, r1, c28, r1, R1, g15, and i3. The r1 fi elds are normally 0; the value 1 implies a /R call sign suffi x to indicate “rover” status in a North American VHF contest. The R1 fi eld conveys the absence (0) or presence (1) of an acknowledgment R before the locator or signal report conveyed by g15. In the fi nal 77-bit information payload, bit fi elds are assembled in the left-to-right order specifi ed in Table 1, followed by n3 (if used; currently used only in type 0) and i3.
We now turn to concise descriptions of the algorithms mapping human-readable message fragments to the tagged bit fi elds with names listed in Table 2. For this purpose the public-domain Fortran programs contained in reference [14] are essential. To get started, download the compressed tarfi le ft4_ft8_protocols.tgz from the www.arrl.org/QEXfi les web page, unpack it into a suitable directory and follow simple instructions for your operating system (Windows, Linux, or macOS) at the top of fi le Makefile. These steps will build executables for the seven programs gen_crc14,
free_text_to_f71, grid4_to_g15, grid6_to_g25,

### hashcodes, nonstd_to_c58, and std_call_to_c28 whose

purposes are explained below.
In alphabetical order, concise defi nitions for the tagged bit fi elds listed in Table 2 are as follows:
c1: | Used only in message type 4. Normally 0; value 1
| denotes a message consisting of CQ and a nonstandard call sign, for example CQ PJ4/K1ABC.
c28: | Used to convey a standard call sign or one of the
| special message words CQ, DE, or QRZ, or a 22-bit
| call sign hash code. CQ may be followed by a modifi er
| with three decimal digits or one to four letters. Each
| possible message fragment with CQ, DE, or QRZ is mapped to a specifi c integer value of c28, as indicated
| in Table 7. Call sign values are computed using the algorithm illustrated by program std_call_to_
| c28, and hash codes by program hashcodes.
c58: | Used to encode nonstandard call signs up to
| 11 characters, using the algorithm illustrated
by program nonstd_to_c58.
f71: | Conveys arbitrary free text with up to 13 characters
| selected from the list

### 0123456789ABCDEFGHIJKLMNOPQRSTUVWXYZ+-./?

| plus the blank character. The encoding algorithm is illustrated by program free_text_to_f71.
g15: | Encodes a 4-character Maidenhead locator, signal
| report, RRR, RR73, 73, or a blank message word,
| using the algorithm in program grid4_to_g15.
g25: | Encodes a 6-character Maidenhead locator using
| the algorithm in program grid6_to_g25.

### h10, h12,Call sign hash codes of length 10, 12, or 22 bits. The

h22: | hashing algorithm is defi ned in program hashcodes.
k3: | ARRL Field Day Class A-F, encoded
| as integer values 0 – 5.
n4: | In message type 0.3, maximum number of
| simultaneously transmitted signals minus 1.
| In message type 0.4, maximum number of
| simultaneously transmitted signals minus 17.
p1: | Absence (0) or presence (1) of call sign suffi x /P.
r1: | Absence (0) or presence (1) of call sign suffi x /R.
r2: | Value 0 encodes a blank message word;
| values 1 – 3 encode RRR, RR73, or 73.
r3: | Values 0 – 7 encode a signal report displayed as 52, 53,
| … 59 (message type 0.3) or 529, 539, … 599 (type 3).
R1: | Absence (0) or presence (1) of
| acknowledgment R before grid or report.
r5: | Values 0 – 31 convey signal reports –30,
| –28, … +32 dB (even numbers only).
s11: | Serial number, range 0 – 2047.
s13: | Values 0 – 7999 convey a serial number; values
| 8001 – 8065 encode the abbreviations for US states
| and Canadian provinces by means of lookup table
| states_provinces.txt included in reference [14].
S7: | Values 0 – 83 encode abbreviations for the ARRL/
| RAC section names by means of lookup table arrl_
| rac_sections.txt included in reference [14].
t1: | Absence (0) or presence (1) of TU; at
| the start of a type 3 message.
t71: | Telemetry data, up to 18 hexadecimal digits
| or 71 bits maximum. With 18 digits, the
| fi rst digit must fall in the range 0 – 7.

We note here that for FT4 only, in order to avoid transmitting a long string of zeros when sending CQ messages, the assembled 77-bit message is bitwise exclusive-OR’ed with the following pseudo-random sequence before computing the CRC and FEC parity bits:
0100101001011110100010
0110110100101100001000
1010011110010101010110
11111000101

The receiving software applies this exclusive-OR procedure a second time, to restore the original 77-bit message.

Table 7 - Summary of mappings between message fragments and numerical values of the bit fi eld c28.

Message fragment | c28 as decimal integer
DE | 0
QRZ | 1
CQ | 2
CQ 000 - CQ 999 | 3 to 1002
CQ A - CQ Z | 1004 to 1029
CQ AA - CQ ZZ | 1031 to 1731
CQ AAA - CQ ZZZ | 1760 to 20685
CQ AAAA - CQ ZZZZ | 21443 to 532443
22-bit hash codes | 2063592 + (0 to 4194303)
Standard call signs | 6257896 + (0 to 268435455)

Steve Franke, K9AN, holds an Amateur Extra class license. He was fi rst licensed in 1971 and has previously held call signs WN9IIQ and WB9IIQ. An early and abiding fascination with radio science led to a 35-year career as Professor of Electrical and Computer Engineering at the University of Illinois. Steve retired in 2019 and now holds the title Professor Emeritus. He enjoys chasing DX, playing with RF circuits and antennas, and studying HF and VHF propagation. Steve is a member of ARRL and a Fellow of the IEEE.

Bill Somerville, G4WJS, earned a Chemistry degree at the University of Bristol and has worked in computer software and hardware in a variety of industries including defense, software development, and fi nancial services. Most recently he’s a freelance consultant providing systems programming and related services to mid- to large-size software tool vendors. An active radio amateur since 1981, Bill enjoys HF and VHF bands, contest operating, and DX chasing using CW, phone, and data modes.

Joe Taylor was fi rst licensed as KN2ITP in 1954, and has since held call signs K2ITP, WA1LXQ, W1HFV, VK2BJX and K1JT. He was Professor of Astronomy at the University of Massachusetts from 1969 to 1981 and since then Professor of Physics at Princeton University, serving there also as Dean of the Faculty for six years. He was awarded the Nobel Prize in Physics in 1993 for discovery of the fi rst orbiting pulsar, leading to observations that established the existence of gravitational waves. After retirement he has been busy developing and enhancing digital protocols for weak-signal communication by Amateur Radio, including JT65 and WSPR. He chases DX from 160 meters through the microwave bands.

References

[1] Joe Taylor, K1JT, Steve Franke, K9AN, and Bill Somerville, G4WJS, “Work the World with WSJT-X: Part 1, Operating Capabilities,” QST, Oct. 2017, pp. 30-36.
[2] Joe Taylor, K1JT, Steve Franke, K9AN, and Bill Somerville, G4WJS, “Work the World with WSJT-X: Part 2, Codes, Modes, and Cooperative Software Development,” QST, Nov. 2017, pp. 34-39.
[3] “Mode Usage Evaluation: 2017 was ‘the Year When Digital Modes Changed Forever’,” www.arrl.org/news/mode-usage-evaluation-2017-was-the-year-when-digital-modes-changed-forever.
[4] Joe Taylor, K1JT, “WSJT: New Software for VHF Meteor-Scatter Communication,” QST, Dec. 2001, pp. 36-41.
[5] Joe Taylor, K1JT, “EME with JT65,” QST, June 2005, pp. 80–82.
[6] Joe Taylor, K1JT, “The JT65 Communications Protocol,” QEX, Sep./Oct. 2005, p. 3-12.
[7] Rex Moncur, VK7MO, and Joe Taylor, K1JT, “Small Station EME at 10 and 24 GHz: GPS Locking, Doppler Correction, and JT4,” Dubus 2/2013.
[8] Steven J. Franke, K9AN, and Joseph H. Taylor, K1JT, “Open Source Soft-Decision Decoder for the JT65 (63,12) Reed-Solomon Code,” QEX, May/June 2016, pp. 8-17.
[9] Steven J. Franke, K9AN, and Joseph H. Taylor, K1JT, “The MSK144 Protocol for Meteor-Scatter Communication,” QEX, July/ Aug. 2017, pp. 8-14.
[10] Nico Palermo, IV3NWV, “Q-ary Repeat-Accumulate Codes for Weak Signals Communications,” www.eme2016.org/wp-content/ uploads/2016/08/EME-2016-IV3NWV-Presentation.pdf.
[11] Joe Taylor, K1JT, “WSJT-X: New Codes, Modes and Tools for Weak-Signal Communication,” www.physics.princeton.edu/ pulsar/K1JT/K1JT_EME_2016_Venice.pdf.
[12] Testing of HF Modems with Bandwidths of up to about 12 kHz Using Ionospheric Channel Simulators, Recommendation ITU-R F.1487, International Telecommunications Union, 2000.
[13] Ross N. Williams, “A Painless Guide to CRC Error Detection Algorithms,” https://www.zlib.net/crc_v3.txt.
[14] http://physics.princeton.edu/pulsar/k1jt/ft4_ft8_protocols. tgz.
[15] Marvin K. Simon and Dariush Divsalar, “Maximum-Likelihood Block Detection of Noncoherent Continuous Phase Modulation,” IEEE Transactions on Communications, Vol. 41, No. 1, Jan. 1993, pp. 90-98.
[16] Shu Lin and Daniel J. Costello, Jr., Error Control Coding: Fundamentals and Applications, 2nd edition. Pearson Prentice Hall, 2004.
[17] Yingquan Wu and Christoforos N. Hadjicostis, “Soft-Decision Decoding of Linear Block Codes Using Preprocessing and Diversifi cation,” IEEE Transactions on Information Theory, Vol. 53, No. 1, Jan. 2007, pp. 378-393.
[18] https://en.wikipedia.org/wiki/UML_state_machine.
[19] WSJT Development Group, “WSJT-X 2.1 User Guide,” www. physics.princeton.edu/pulsar/K1JT/wsjtx-doc/wsjtx-main-2.1.2.html.
[20] GNU General Public License, GPLv3, https://www.gnu.org/licenses/gpl-3.0.txt. See also https://en.wikipedia.org/wiki/GNU_General_Public_License.

Reprinted with permission; copyright ARRL.

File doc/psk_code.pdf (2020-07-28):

PSK31 (Phase Shift Keying) | Anthony : F4GOH
Features (standard): | No Standard Tones
Phase modulation
Speed : 31 bauds
1/31 s for 1 Bit
Transmission: Synchronous | Variable data bits between 2 idle states
Character set: Varicode (the transmission time varies depending on content)

Slow, The whole ASCII table is represented.
No check code. 31hz bandwidth.

Usual frequencies:
14,073 Mhz
7,037 Mhz
The letters are coded by a sequence of bits of variable length, as in the Morse alphabet. This coding called Varicode was invented by 2 radio amateurs in 1990. http://en.wikipedia.org/wiki/Varicode
Varicode Character
1 | SP
111111111 | !
101011111 | "
111110101 | #
111011011 | $
1011010101 | %
1010111011 | &
101111111 | '
11111011 | (
11110111 | )
101101111 | *
111011111 | +
1110101 | ,
110101 | -
1010111 | .

Varicode Character
1010111101 | @
1111101 | A
11101011 | B
10101101 | C
10110101 | D
1110111 | E
11011011 | F
11111101 | G
101010101 | H
1111111 | I
111111101 | J
101111101 | K
11010111 | L
10111011 | M
11011101 | N

Varicode Character
1011011111 | `
1011 | a
1011111 | b
101111 | c
101101 | d
11 | e
111101 | f
1011011 | g
101011 | h
1101 | i
111101011 | j
10111111 | k
11011 | l
111011 | m
1111 | n

Varicode coding is
studied in order to
reduce the number of
bits transmitted for the
most used characters.

For example the "e" is
coded on 2 bits.
The 1-bit space
character.
The @ character is not
widely used, so it will
be encoded in a larger
number of bits.
The list of codes is not
complete, but gives an
overview.

Example of PSK31 frame: Send the word "test" then CR (carriage return)

Description:
We start by sending successive idle states (R), then as soon as the signal remains stable (of the same phase) an NL1 is transmitted, then it is a phase inversion and it is the turn of an NL0 . We finish each character by adding an NL0 because it is necessary to place the rest states R between each letter. This is why the frame clock corresponds directly to the idle states. The transmission is synchronous. To avoid the generation of too large harmonics,
the amplitude is reduced before reversing the phase.


For the PSK63 (63 bauds) and PSK125 (125 Bauds), the coding principle remains the same.

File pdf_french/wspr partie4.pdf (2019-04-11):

# Amplificateur et filtre HF


WSPRwhisper : Weak Signal Propagation Reporter


WSPRSynoptique


## Ou se procurer les tores ? https://www.kitsandparts.com/store2.php


# Classes de fonctionnement d'un amplificateur


fr.wikipedia.org (https://fr.wikipedia.org/wiki/Classes_de_fonctionnement_d%27un_amplificateur_%C3%A9lectronique)

•1 Introduction (https://fr.wikipedia.org/wiki/Classes_de_fonctionnement_d%27un_amplificateur_%C3%A9lectronique)
•2 Classe A (https://fr.wikipedia.org/wiki/Classes_de_fonctionnement_d%27un_amplificateur_%C3%A9lectronique)
•3 Classe B (https://fr.wikipedia.org/wiki/Classes_de_fonctionnement_d%27un_amplificateur_%C3%A9lectronique)
•4 Classe AB (https://fr.wikipedia.org/wiki/Classes_de_fonctionnement_d%27un_amplificateur_%C3%A9lectronique)
•5 Classe C (https://fr.wikipedia.org/wiki/Classes_de_fonctionnement_d%27un_amplificateur_%C3%A9lectronique)
•6 Classe D (https://fr.wikipedia.org/wiki/Classes_de_fonctionnement_d%27un_amplificateur_%C3%A9lectronique)
•7 Classe E (https://fr.wikipedia.org/wiki/Classes_de_fonctionnement_d%27un_amplificateur_%C3%A9lectronique)
•8 Classe F (https://fr.wikipedia.org/wiki/Classes_de_fonctionnement_d%27un_amplificateur_%C3%A9lectronique)
•9 Classe G (https://fr.wikipedia.org/wiki/Classes_de_fonctionnement_d%27un_amplificateur_%C3%A9lectronique)
•10 Classe H (https://fr.wikipedia.org/wiki/Classes_de_fonctionnement_d%27un_amplificateur_%C3%A9lectronique)
•11 Classe S (https://fr.wikipedia.org/wiki/Classes_de_fonctionnement_d%27un_amplificateur_%C3%A9lectronique)

## -Bon rendement -Distorsion catastrophique

## Filtrage obligatoire


Etude du filtre passe bas du 5-ème ordre : http://tonnesoftware.com/svcdownload.html


Dimensionnement des composants: | Rappel :
| 1 er ordre : -20 dB par décade 2 -ème ordre : -40 dB par décade Etc.. 1 er ordre : -6 dB par octave 5 -ème ordre : -30 dB par octave

## Réalisation des inductances


Mini tore calculator (https://constructions.f6fkn.com/downloads/minirk12-install.exe)

# Analyse du filtre au VNA


# Câblage de l’ensemble


## Amplificateur et filtre HF

# Essais sur 40m


# Dernière séance : Réalisation sur un circuit imprimé


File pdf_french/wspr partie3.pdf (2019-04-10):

# Oscillateur programmable DDS


WSPRwhisper : Weak Signal Propagation Reporter

# Protocole WSPR


WSPRSynoptique

## DDS = Direct Digital Synthesis


## Pour en savoir plus sur le DDS


http://kudelsko.free.fr/generateur_fonctions/principe_dds.htmhttps://www.arrow.com/fr-fr/research-and-events/videos/what-is-direct-digital-synthesishttp://www.johnlo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
Standalone HAM modulation generator (DDS : Structure interne) https://www.tapr.org/https://github.com/f4goh/WSPR


# WSPR : L’encodeur



## 162 x 0,682 = 110,484 soit 1 minute et 50 secondes

# WSPR, la théorie Andy Talbot : http://www.g4jnt.com/wspr_coding_process.pdf


# Mise en pratique


- Générer vos symboles avec WSPR encoder.exe https://github.com/f4goh/WSPR
- Coller les symboles dans le code Arduino wsprSimple.ino
- Téléverser le programme dans l’arduino nano (Attention au port COM)
- Placer un bout de fil en l’air sur la sortie sinus du DDS, SinA ou SinB
- Décoder la trame avec WSJT-X


# La prochaine séance


## Amplificateur et filtre HF


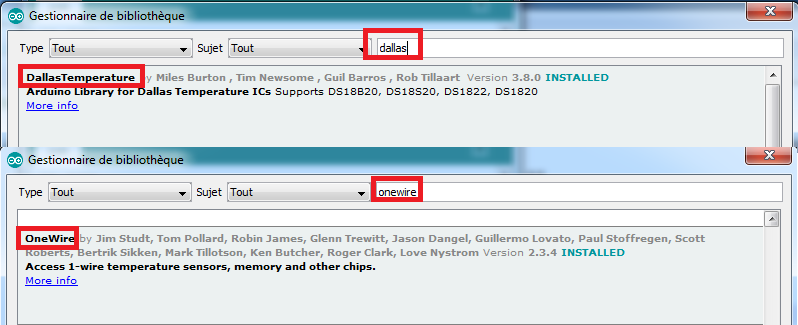
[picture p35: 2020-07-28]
img/library.png

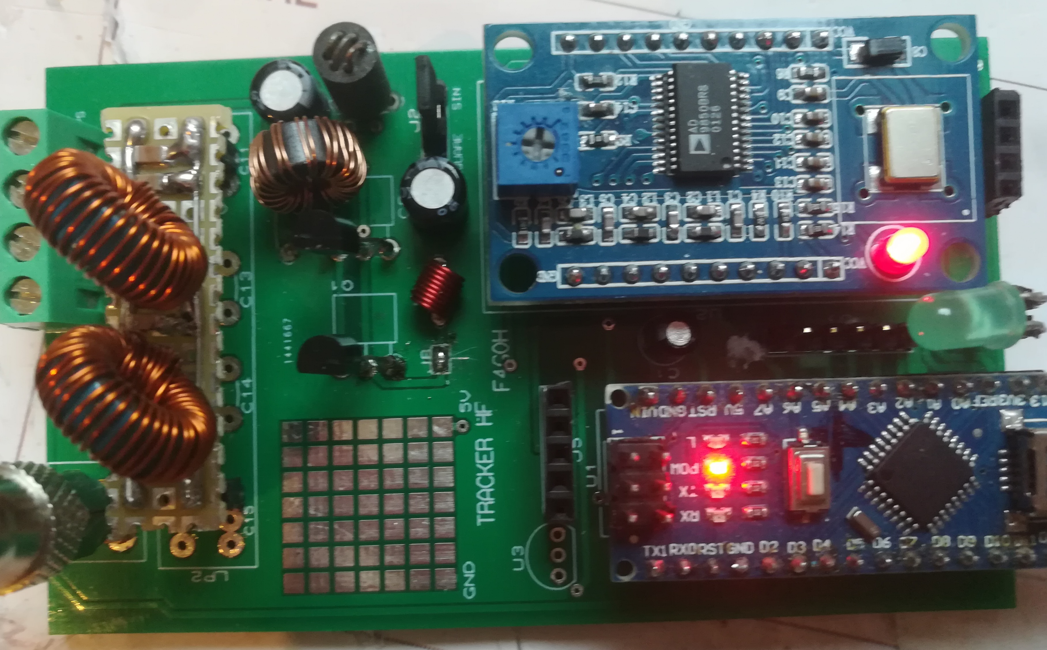
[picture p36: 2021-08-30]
src/IK1HGI/IMG/board.jpg

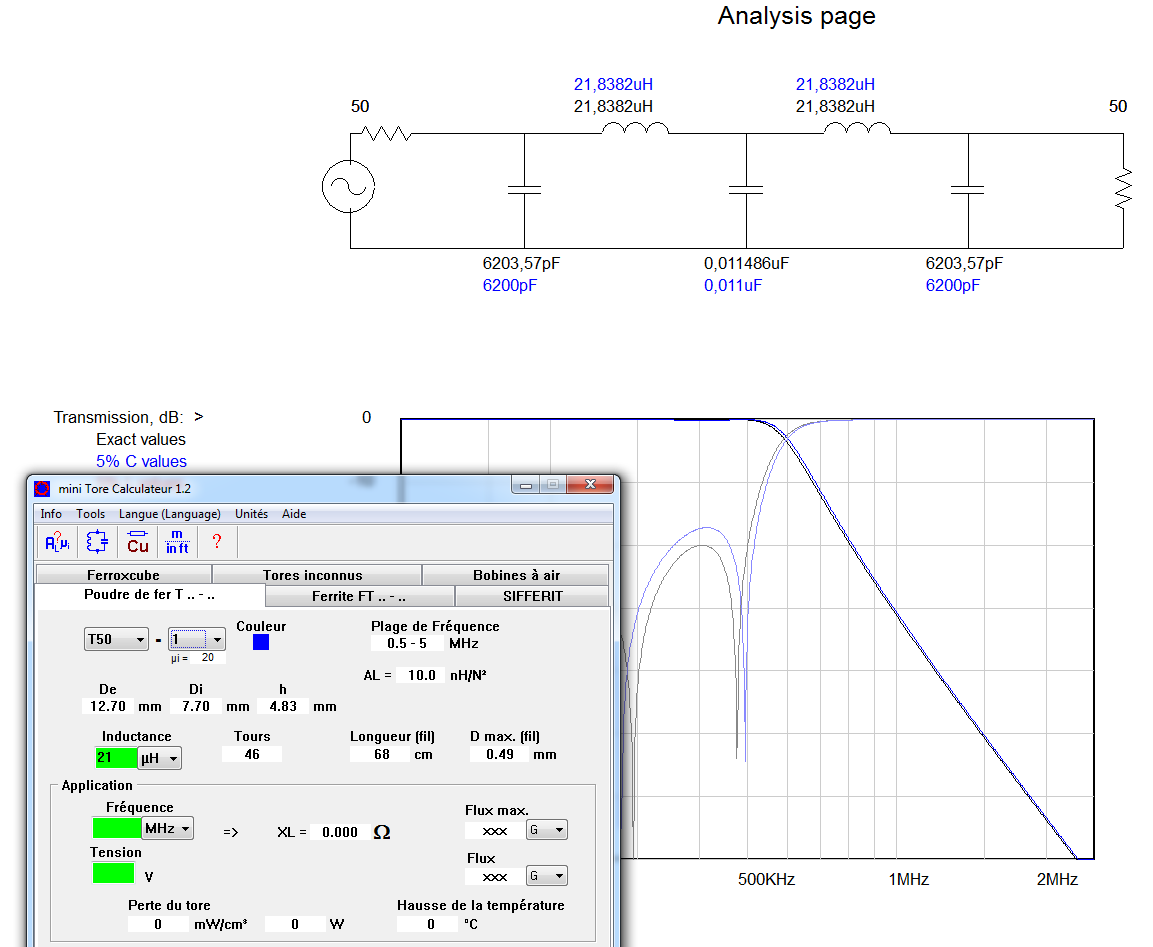
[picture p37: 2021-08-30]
src/IK1HGI/IMG/630m filter.png

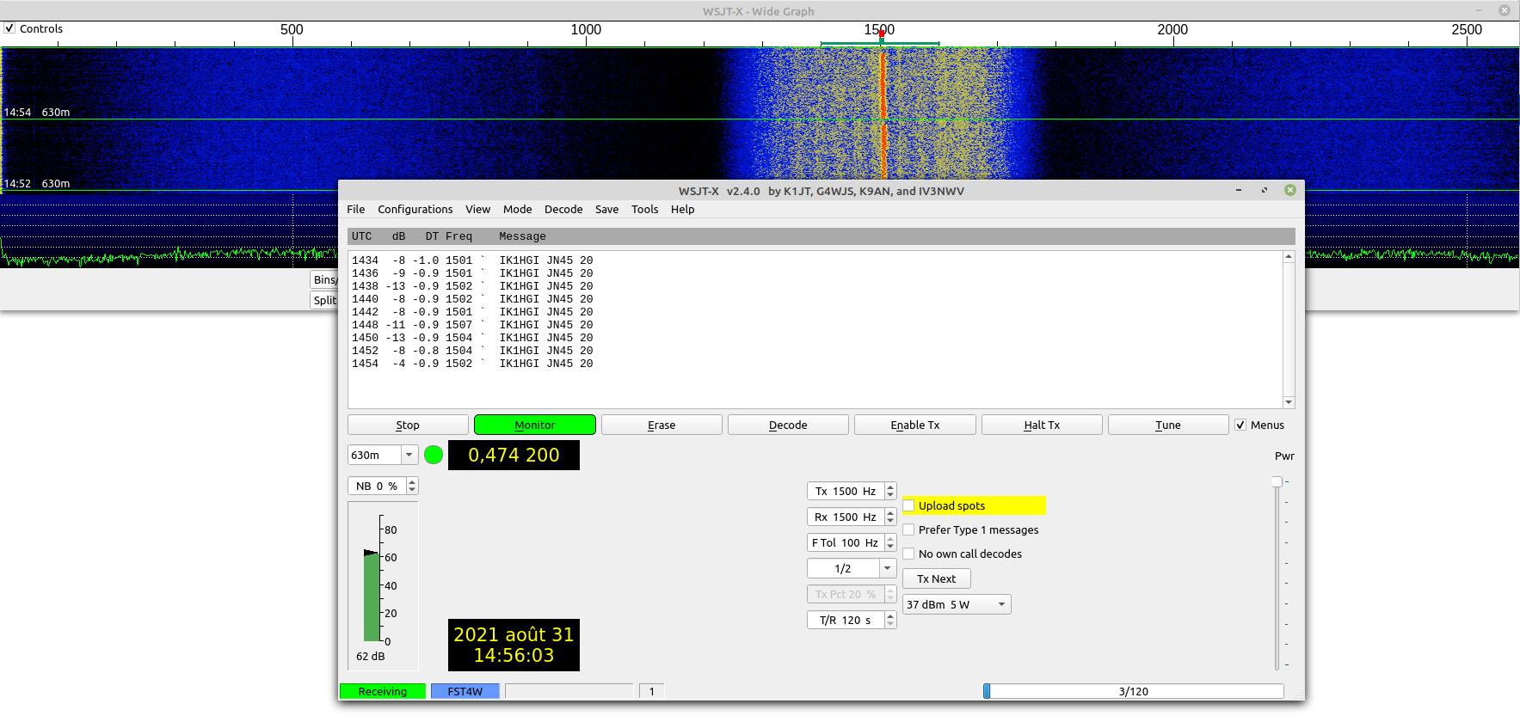
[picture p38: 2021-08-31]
src/IK1HGI/IMG/fst4w_decode.png

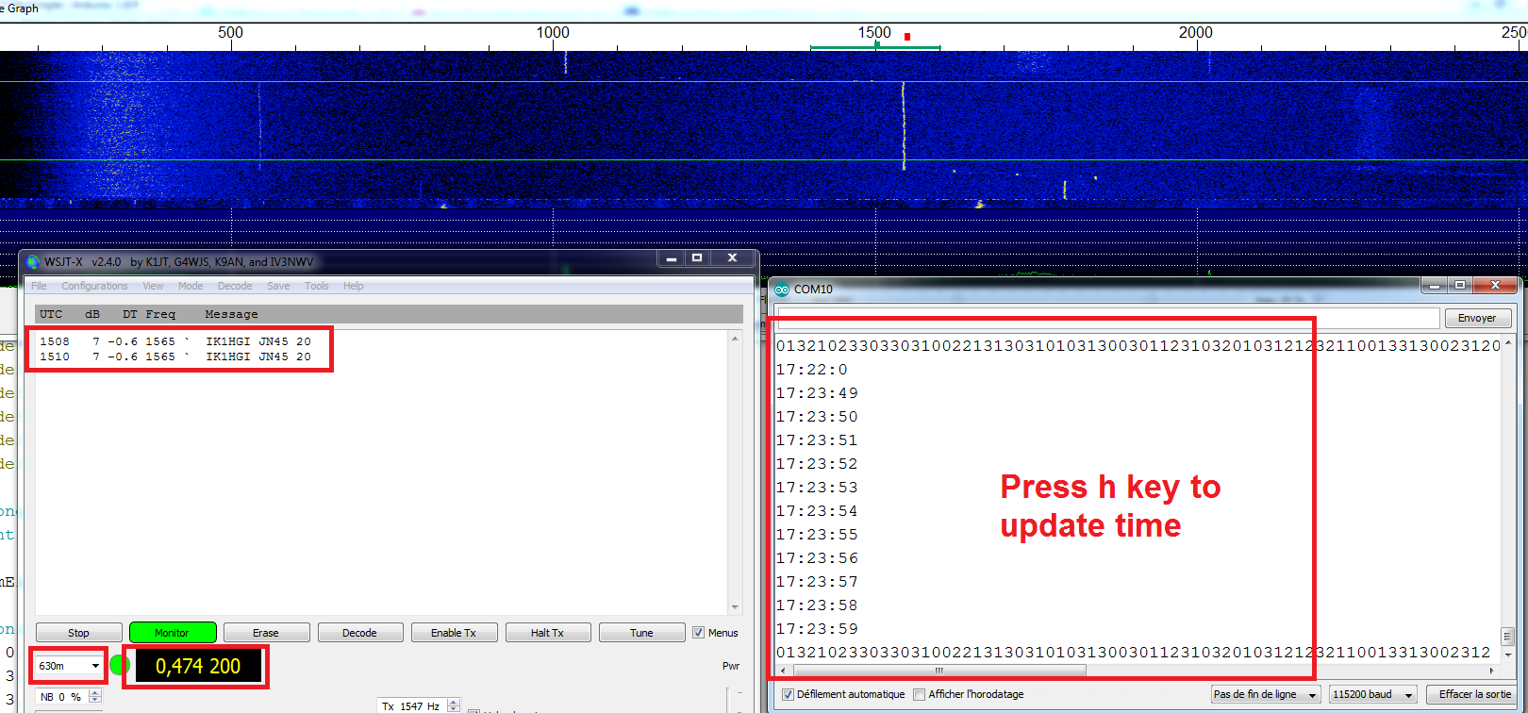
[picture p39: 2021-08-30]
src/IK1HGI/IMG/decode.png

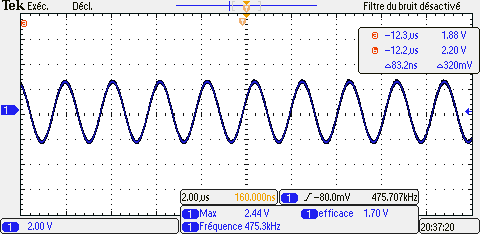
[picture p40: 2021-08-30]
src/IK1HGI/IMG/Sin_out.PNG

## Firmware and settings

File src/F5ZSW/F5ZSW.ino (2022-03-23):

/*sample code for F5ZSW
  Anthony LE CREN F4GOH@orange.fr
  Created 23/3/2022
  the program send cw and ft8 sequence 4 times per minutes
  with GPS to have perfect timing
*/


#include <SPI.h>
#include <JTEncode.h>
#include <SoftwareSerial.h>
#include <TinyGPS.h>


//NANO pinout
#define txPin 5 //tx pin into RX GPS connection
#define rxPin 4 //rx pin into TX GPS connection
#define LED 8   //output pin led
#define GAIN 6  //pwm output to adjust gain (mos polarization)
#define SENSOR 7  //ds18s20 sensor
#define PTT A0  //ds18s20 sensor
#define W_CLK 13  //ad9850 clk
#define FQ_UD 10  //ad9850 update
#define RESET 9  // ad9850 reset
#define MOSI 11  // 

//#define debugGPS //enable print all nmea sentences on serial monitor
#define debugDDS //enable debug DDS with some key commands as 0,1,2,3 on serial monitor (see debug function)
//#define debugSYMBOLS

#define CW_FREQUENCY 10133000  //same fequency for test
#define FT8_FREQUENCY 10133000  //

#define CW_TXT " VVV F5ZSW JN23MK"

#define CALL "F5ZSW"        //callsign
#define DBM 20              //power in dbm
#define GPS_BAUD_RATE 9600
#define PC_BAUD_RATE  115200
#define PWM_GAIN 140      //continous voltage ctrl for mosfet 110=1.2V  -> 1K and 4.7K (210)

#define WSPR_TONE_SPACING       1.4548
#define WSPR_DELAY              682
#define MESSAGE "CQ F5ZSW JN23"
#define FT8_TONE_SPACING        6.25f
#define FT8_DELAY               160

SoftwareSerial ss(rxPin, txPin); // RX, TX for GPS
JTEncode jtencode;
TinyGPS gps;


enum mode {
  CW,
  FT8_CQ,
};

byte tableSeconds[] = {0, 15, 30, 45}; //seconds to transmit
mode tableMode[] = {CW, CW, CW, FT8_CQ};

long factor = -1500;		//adjust frequency to wspr band
uint8_t symbols[WSPR_SYMBOL_COUNT];    //buffer memeory for WSPR or ft8 encoding

typedef struct
{
  char locator[9];   /*!< locator */
  uint8_t pwrDbm;
} position;

position pos;

int gain = PWM_GAIN;


void setup() {
  Serial.begin(PC_BAUD_RATE);
  Serial.print("Hello ");
  Serial.println(CALL );
  pinMode(LED, OUTPUT);
  pinMode(GAIN, OUTPUT);
  pinMode(MOSI, INPUT);
  pinMode(PTT, OUTPUT);
  digitalWrite(PTT, LOW);
  analogWrite(GAIN, 0);
  ss.begin(GPS_BAUD_RATE);
  delay(2000);
  initDds();
  setfreq(0, 0);
  setfreq(0, 0);
  //latlng2loc(48.605776, -4.550759, 0);
  //Serial.print("LOCATOR : ");
  //Serial.println(pos.locator);
  //Serial.println(pos.pwrDbm);


}


//main loop
void loop() {

#ifdef debugDDS
  char c;
  if (Serial.available() > 0) {
    c = Serial.read();
    Serial.println(c);
    debug(c);
  }
#endif
  lectGps();
}


/********************************************************
  WSPR loop with time sync
 ********************************************************/

void  lectGps()
{
  bool newData = false;

  // for (unsigned long start = millis(); millis() - start < 1000;)
  // {
  while (ss.available())
  {
    char c = ss.read();
#ifdef debugGPS
    Serial.write(c);
#endif
    if (gps.encode(c)) // Did a new valid sentence come in?
      newData = true;
  }
  // }
  if (newData)
  {
    unsigned long age;
    int year;
    byte month, day, hour, minute, second, hundredths;
    gps.crack_datetime(&year, &month, &day, &hour, &minute, &second, &hundredths, &age);
    if (age == TinyGPS::GPS_INVALID_AGE)
      Serial.println("*******    *******    ");
    else
    {
      char sz[32];
      char index;
      sprintf(sz, "%02d:%02d:%02d   ", hour, minute, second);
      Serial.println(sz);
      digitalWrite(LED, digitalRead(LED) ^ 1);
      index = syncSeconds(second);
      if ((index >= 0)  && (second % 15 == 0)) {
        mode mtx = tableMode[index];
        switch (mtx) {
          case CW :
            txCW(CW_FREQUENCY, CW_TXT, 30);
            break;
          case FT8_CQ :
            txFt8(FT8_CQ);
            break;
        }
      }
    }
  }
}

char syncSeconds(int m) {
  int i;
  char ret = -1;
  for (i = 0; i < sizeof(tableSeconds); i++) {
    if (m == tableSeconds[i]) {
      ret = i;
    }
  }
  return ret;
}

/********************************************************
  Debug function
********************************************************/


void debug(char c)
{
  switch (c)
  {
    case 'c' :
      txCW(CW_FREQUENCY, CW_TXT, 30);
      break;
    case 'f' :
      txFt8(FT8_CQ);    //ft8 cq
      break;
    case '0' :
      analogWrite(GAIN, 0);
      setfreq(0, 0);
      ddsPowerOff();
      digitalWrite(PTT, LOW);
      break;
    case '1' :  ddsPowerOn();
      setfreq(CW_FREQUENCY, 0);  //test avec dds pw off
      analogWrite(GAIN, gain);
      digitalWrite(PTT, HIGH);
      break;
    case '2' :  factor += 100;
      Serial.println(factor);
      break;
    case '3' :  factor -= 100;
      Serial.println(factor);
      break;

    case '4' :  gain += 10;
      Serial.println(gain);
      analogWrite(GAIN, gain);
      break;
    case '5' :  gain -= 10;
      Serial.println(gain);
      analogWrite(GAIN, gain);
      break;

    case 'l' :
      latlng2loc(47.890242, 0.276770, 0);
      Serial.println(pos.locator);
      Serial.println(pos.pwrDbm);
      Serial.flush();
      break;
    case 'd' :
      initDds();
      break;
  }
}
/**************************
   cw
 **************************/
void txCW(long freqCw, char * stringCw, int cwWpm) {
  const static int morseVaricode[2][59] PROGMEM = {
    {0, 212, 72, 0, 144, 0, 128, 120, 176, 180, 0, 80, 204, 132, 84, 144, 248, 120, 56, 24, 8, 0, 128, 192, 224, 240, 224, 168, 0, 136, 0, 48, 104, 64, 128, 160, 128, 0, 32, 192, 0, 0, 112, 160, 64, 192, 128, 224, 96, 208, 64, 0, 128, 32, 16, 96, 144, 176, 192},
    {7, 6, 5, 0, 4, 0, 4, 6, 5, 6, 0, 5, 6, 6, 6, 5, 5, 5, 5, 5, 5, 5, 5, 5, 5, 5, 6, 6, 0, 5, 0, 6, 6, 2, 4, 4, 3, 1, 4, 3, 4, 2, 4, 3, 4, 2, 2, 3, 4, 4, 3, 3, 1, 3, 4, 3, 4, 4, 4}
  };

  int tempo = 1200 / cwWpm; // Duration of 1 dot
  byte nb_bits, val;
  int d;
  int c = *stringCw++;
  Serial.println("CW TX");
  digitalWrite(PTT, HIGH);
  delay(10);
  analogWrite(GAIN, PWM_GAIN);
  while (c != '\0') {
    c = toupper(c); // Uppercase
    if (c == 32) {     // Space character between words in string
      setfreq(0, 0); // 7 dots length spacing
      delay(tempo * 7); // between words
    }
    else if (c > 32 && c < 91) {
      c = c - 32;
      d = int(pgm_read_word(&morseVaricode[0][c]));    // Get CW varicode
      nb_bits = int(pgm_read_word(&morseVaricode[1][c])); // Get CW varicode length
      if (nb_bits != 0) { // Number of bits = 0 -> invalid character #%<>
        for (int b = 7; b > 7 - nb_bits; b--) { // Send CW character, each bit represents a symbol (0 for dot, 1 for dash) MSB first
          val = bitRead(d, b); //look varicode
          setfreq(freqCw, 0); // Let's transmit
          delay(tempo + 2 * tempo * val);  // A dot length or a dash length (3 times the dot)

          setfreq(0, 0); // 1 dot length spacing
          delay(tempo);     // between symbols in a character
        }
      }
      setfreq(0, 0); // 3 dots length spacing
      delay(tempo * 3); // between characters in a word
    }
    c = *stringCw++;  // Next caracter in string
  }
  digitalWrite(PTT, LOW);
  analogWrite(GAIN, 0);
  setfreq(0, 0);
  Serial.println("EOT");
}



/**************************
   ft8
 **************************/

void txFt8(mode mtx) {
  char message[14];
  float flat, flon;
  unsigned long age;
  Serial.println("CW FT8");
  gps.f_get_position(&flat, &flon, &age);
  Serial.print("LAT=");
  Serial.print(flat == TinyGPS::GPS_INVALID_F_ANGLE ? 0.0 : flat, 6);
  Serial.print(" LON=");
  Serial.println(flon == TinyGPS::GPS_INVALID_F_ANGLE ? 0.0 : flon, 6);
  latlng2loc(flat, flon, 1);
  sprintf(message, "CQ %s %s", CALL, pos.locator);

  Serial.println(message);
  memset(symbols, 0, FT8_SYMBOL_COUNT);   //clear memory
  jtencode.ft8_encode(message, symbols);
#ifdef debugSYMBOLS
  int n, lf;
  lf = 0;
  for (n = 0; n < FT8_SYMBOL_COUNT; n++) {   //print symbols on serial monitor
    if (lf % 16 == 0) {
      Serial.println();
      Serial.print(n);
      Serial.print(": ");
    }
    lf++;
    Serial.print(symbols[n]);
    Serial.print(',');
  }
  Serial.println();
#endif
  sendFt8(FT8_FREQUENCY);
}

void sendFt8(long freq) {
  int a = 0;
  digitalWrite(PTT, HIGH);
  delay(10);
  analogWrite(GAIN, PWM_GAIN);
  for (int element = 0; element < FT8_SYMBOL_COUNT; element++) {    // For each element in the message
    a = int(symbols[element]); //   get the numerical ASCII Code
    setfreq((double) freq + (double) a * FT8_TONE_SPACING, 0);
    delay(FT8_DELAY);
#ifdef debugSYMBOLS
    Serial.print(a);
#endif
    digitalWrite(LED, digitalRead(LED) ^ 1);
  }
  digitalWrite(PTT, LOW);
  analogWrite(GAIN, 0);
  setfreq(0, 0);
  Serial.println("EOT");
}





/********************************************************
  AD9850 routines
********************************************************/


void initDds()
{
  pinMode(MOSI, OUTPUT);
  delay(10);
  SPI.begin();
  pinMode(W_CLK, OUTPUT);
  pinMode(FQ_UD, OUTPUT);
  pinMode(RESET, OUTPUT);

  SPI.setBitOrder(LSBFIRST);
  SPI.setDataMode(SPI_MODE0);

  pulse(RESET);
  pulse(W_CLK);
  pulse(FQ_UD);
  setfreq(0, 0);
  setfreq(0, 0);
}

void pulse(int pin) {
  digitalWrite(pin, HIGH);
  // delay(1);
  digitalWrite(pin, LOW);
}


void setfreq(double f, uint16_t p) {
  uint32_t deltaphase;

  deltaphase = f * 4294967296.0 / (125000000 + factor);
  for (int i = 0; i < 4; i++, deltaphase >>= 8) {
    SPI.transfer(deltaphase & 0xFF);
  }
  SPI.transfer((p << 3) & 0xFF) ;
  pulse(FQ_UD);
}

void ddsPowerOn() {
  setfreq(0, 0);
}

void ddsPowerOff() {
  pulse(FQ_UD);
  SPI.transfer(0x04);
  pulse(FQ_UD);
}

/********************************************************
  locator calculator
********************************************************/

void latlng2loc(float lat, float lng, byte nb)
{
  const uint8_t valid_dbm[19] = {0, 3, 7, 10, 13, 17, 20, 23, 27, 30, 33, 37, 40, 43, 47, 50, 53, 57, 60};
  lat += 90; // lat origin of Maidenhead is 90S
  lng += 180; // lng origin of Maidenhead is 180W
  double units = 43200; // 18 fields * 10 squares * 24 subsquares * 10 extended square
  int xLong, yLat, indice, dbm;
  // get the extended sq
  lat = floor(lat * units / 180.0);
  lng = floor(lng * units / 360.0);
  pos.locator[6] = (long(lng) % 10) + '0';
  pos.locator[7] = (long(lat) % 10) + '0';
  lat = floor(lat / 10);
  lng = floor(lng / 10);
  xLong = long(lng) % 24;
  yLat = long(lat) % 24;
  indice = (xLong / 4) * 3 + (yLat / 8);
  pos.pwrDbm = valid_dbm[indice];
  pos.locator[4] = xLong + 'A';
  pos.locator[5] = yLat + 'A';
  // get the sq.
  lat = floor(lat / 24);
  lng = floor(lng / 24);
  pos.locator[2] = (long(lng) % 10) + '0';
  pos.locator[3] = (long(lat) % 10) + '0';
  // get the fields
  lat = floor(lat / 10);
  lng = floor(lng / 10);
  pos.locator[0] = long(lng) + 'A';
  pos.locator[1] = long(lat) + 'A';
  if (nb == 0) {
    pos.locator[8] = '\0';
  }
  else
  {
    pos.locator[4] = '\0';
  }
}

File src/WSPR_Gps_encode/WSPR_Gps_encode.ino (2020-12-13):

/* wspr with encode
  Anthony LE CREN F4GOH@orange.fr
  Created 13/12/2020
  the program send wspr sequence 3 times per hour
  with GPS to have perfect even minutes
  cc-by-nc-sa
  WSPR  Symbol exemple
  0: 3,3,0,2,0,2,0,2,1,0,0,0,3,3,1,0,
  16: 2,0,3,2,0,3,2,3,1,1,1,0,2,0,0,2,
  32: 0,2,3,0,0,3,2,1,0,2,0,0,2,0,3,2,
  48: 1,1,2,2,3,3,2,1,2,0,2,3,3,0,1,0,
  64: 2,0,2,3,1,2,1,2,3,0,1,2,3,0,0,3,
  80: 2,0,1,2,1,1,0,0,0,1,3,2,1,0,1,0,
  96: 2,2,3,0,0,2,2,2,3,0,0,3,2,2,3,3,
  112: 1,0,3,3,0,0,1,3,0,1,2,0,0,3,3,1,
  128: 2,0,0,0,2,3,0,3,2,0,3,1,2,2,0,0,
  144: 2,2,2,1,3,0,1,0,1,3,2,0,0,3,1,0,
  160: 2,2,
*/


#include <SPI.h>
#include <JTEncode.h>
#include <SoftwareSerial.h>

//NANO pinout
#define txPin 5 //tx pin into RX GPS connection
#define rxPin 4 //rx pin into TX GPS connection
#define LED 8   //output pin led
#define GAIN 6  //pwm output to adjust gain (mos polarization)
#define W_CLK 13  //ad9850 clk
#define FQ_UD 10  //ad9850 update
#define RESET 9  // ad9850 reset

//#define debugGPS //enable print all nmea sentences on serial monitor
//#define debugDDS //enable debug DDS with some key commands as 0,1,2,3 on serial monitor (see debug function)

//#define FREQUENCY 10140170  //30m
#define FREQUENCY 7040100
//#define FREQUENCY 3570100  //80m

#define CALL "KF4GOH"        //callsign
#define DBM 20              //power in dbm
#define GPS_BAUD_RATE 9600
#define PC_BAUD_RATE  115200
#define PWM_GAIN 110      //continous voltage ctrl for mosfet 110=1.2V

#define WSPR_TONE_SPACING       1.4548
#define WSPR_DELAY              682
#define ZONESEGMENT    20.0
#define FIELDSEGMENT  10.0
#define SQUARESEGMENT 10.0
#define NBSQUARE    24.0

SoftwareSerial gps(rxPin, txPin); // RX, TX for GPS
JTEncode jtencode;

int tableMinutes[] = {0, 2, 4, 20, 22, 24, 40, 42, 44};   //minutes to transmit WSPR

long factor = -1500;		//adjust frequency to wspr band
uint8_t wsprSymb[WSPR_SYMBOL_COUNT];    //buffer memeory for WSPR encoding

String time;          //GPS Strings for parser
String time_prec;
String flag;
String date;
String lat;
String ns;
String lon;
String ew;
String spd;
String alt;
String course;
String sats;


void setup() {

  Serial.begin(PC_BAUD_RATE);
  Serial.print("Hello ");
  Serial.println(CALL );
  pinMode(LED, OUTPUT);
  pinMode(GAIN, OUTPUT);
  analogWrite(GAIN, 0);
  gps.begin(GPS_BAUD_RATE);
  delay(1000);
  initDds();
  setfreq(0, 0);
  setfreq(0, 0);
}


//main loop
void loop() {

#ifdef debugDDS
  char c;
  if (Serial.available() > 0) {
    c = Serial.read();
    Serial.println(c);
    debug(c);
  }
#endif
  lectGps();
}

/********************************************************
  WSPR loop with time sync
 ********************************************************/

void  lectGps()
{
  int minutes;
  int secondes;
  if (getGps()) {
    if (time != time_prec) {
      time_prec = time;
      digitalWrite(LED, digitalRead(LED) ^ 1);

      minutes = time.substring(2, 4).toInt();
      secondes = time.substring(4, 6).toInt();
      Serial.println(time);

      if ((syncMinutes(minutes) == true)  && (secondes == 0)) {
        txWspr();
      }
#ifdef debugGPS
      printGps();
#endif
    }
  }
}

boolean syncMinutes(int m) {
  int i;
  boolean ret = false;
  for (i = 0; i < sizeof(tableMinutes); i++) {
    if (m == tableMinutes[i]) {
      ret = true;
    }
  }
  return ret;
}

void txWspr() {
  char loc[7];
  locator(lon, ew, lat, ns, 1).toCharArray(loc, 7);
  Serial.println(loc);
  //wspr(FREQUENCY, "F4GOH", loc, "20");
  memset(wsprSymb, 0, WSPR_SYMBOL_COUNT);   //clear memory
  jtencode.wspr_encode(CALL, loc, DBM, wsprSymb); //encode WSPR
  int n, lf;
  lf = 0;
  for (n = 0; n < WSPR_SYMBOL_COUNT; n++) {   //print symbols on serial monitor
    if (lf % 16 == 0) {
      Serial.println();
      Serial.print(n);
      Serial.print(": ");
    }
    lf++;
    Serial.print(wsprSymb[n]);
    Serial.print(',');
  }
  Serial.println();
  sendWspr(FREQUENCY);
}

void sendWspr(long freqWspr) {

  int a = 0;
  analogWrite(GAIN, PWM_GAIN);
  for (int element = 0; element < 162; element++) {    // For each element in the message
    a = int(wsprSymb[element]); //   get the numerical ASCII Code
    setfreq((double) freqWspr + (double) a * WSPR_TONE_SPACING, 0);
    delay(WSPR_DELAY);
    Serial.print(a);
    digitalWrite(LED, digitalRead(LED) ^ 1);
  }
  analogWrite(GAIN, 0);
  setfreq(0, 0);
  Serial.println("EOT");
}

/********************************************************
  Debug function
 ********************************************************/


void debug(char c)
{
  switch (c)
  {
    case 'w' :
      txWspr();
      break;
    case '0' :  setfreq(0, 0);
      ddsPowerOff();
      break;
    case '1' :  ddsPowerOn();
      setfreq(FREQUENCY, 0);  //teste avec dds pw off
      break;
    case '2' :  factor += 100;
      Serial.println(factor);
      break;
    case '3' :  factor -= 100;
      Serial.println(factor);
      break;
  }
}


/********************************************************
  AD9850 routines
 ********************************************************/


void initDds()
{
  SPI.begin();
  pinMode(W_CLK, OUTPUT);
  pinMode(FQ_UD, OUTPUT);
  pinMode(RESET, OUTPUT);

  SPI.setBitOrder(LSBFIRST);
  SPI.setDataMode(SPI_MODE0);

  pulse(RESET);
  pulse(W_CLK);
  pulse(FQ_UD);

}

void pulse(int pin) {
  digitalWrite(pin, HIGH);
  // delay(1);
  digitalWrite(pin, LOW);
}


void setfreq(double f, uint16_t p) {
  uint32_t deltaphase;

  deltaphase = f * 4294967296.0 / (125000000 + factor);
  for (int i = 0; i < 4; i++, deltaphase >>= 8) {
    SPI.transfer(deltaphase & 0xFF);
  }
  SPI.transfer((p << 3) & 0xFF) ;
  pulse(FQ_UD);
}

void ddsPowerOn() {
  setfreq(0, 0);
}

void ddsPowerOff() {
  pulse(FQ_UD);
  SPI.transfer(0x04);
  pulse(FQ_UD);
}


/********************************************************
  GPS nmea parser
 ********************************************************/

String readParamGps() {
  return  gps.readStringUntil(',');
}
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

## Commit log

2019-03-23 WSPR beacon
    usage notes and drivers
    [schema complet.fzz]
2020-09-01 update
    mistake on dbm define
    [wsprEncode.ino]
